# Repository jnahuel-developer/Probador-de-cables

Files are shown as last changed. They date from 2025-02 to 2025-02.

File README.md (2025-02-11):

# 🛠️ Probador de Cables  

Dispositivo para probar y validar el correcto funcionamiento de los cables que se usan en los equipos productivos.  
Este repositorio incluye tanto el firmware para el microcontrolador como el diseño del PCB.  

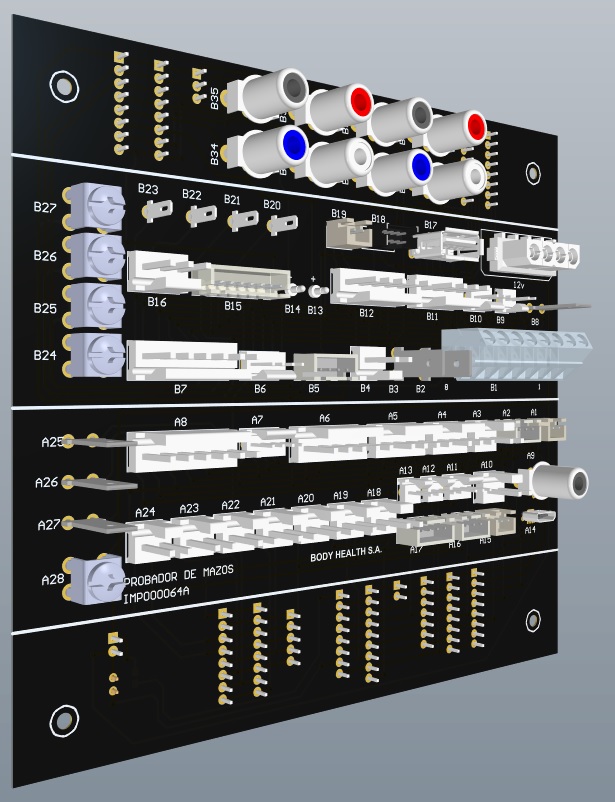
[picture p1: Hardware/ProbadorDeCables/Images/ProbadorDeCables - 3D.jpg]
Vista 3D del PCB
  

---
---

## Funcionamiento  

 Este proyecto se puede anexar al [Probador de manillares](https://github.com/jnahuel-developer/Probador-de-manillares-de-crio), para hacer uso de sus multiplexores analógicos.  
 Gracias a ellos, se puede obtener una matriz de continuidad, y analizarla según el cable en cuestión.  
 Esto permite detectar todo tipo de anormalidades, como cortocircuitos, cables cortados, o mala ubicación de algunos contactos.  

## Ejemplo de cable utilizado

Diagrama eléctrico realizado en Altium

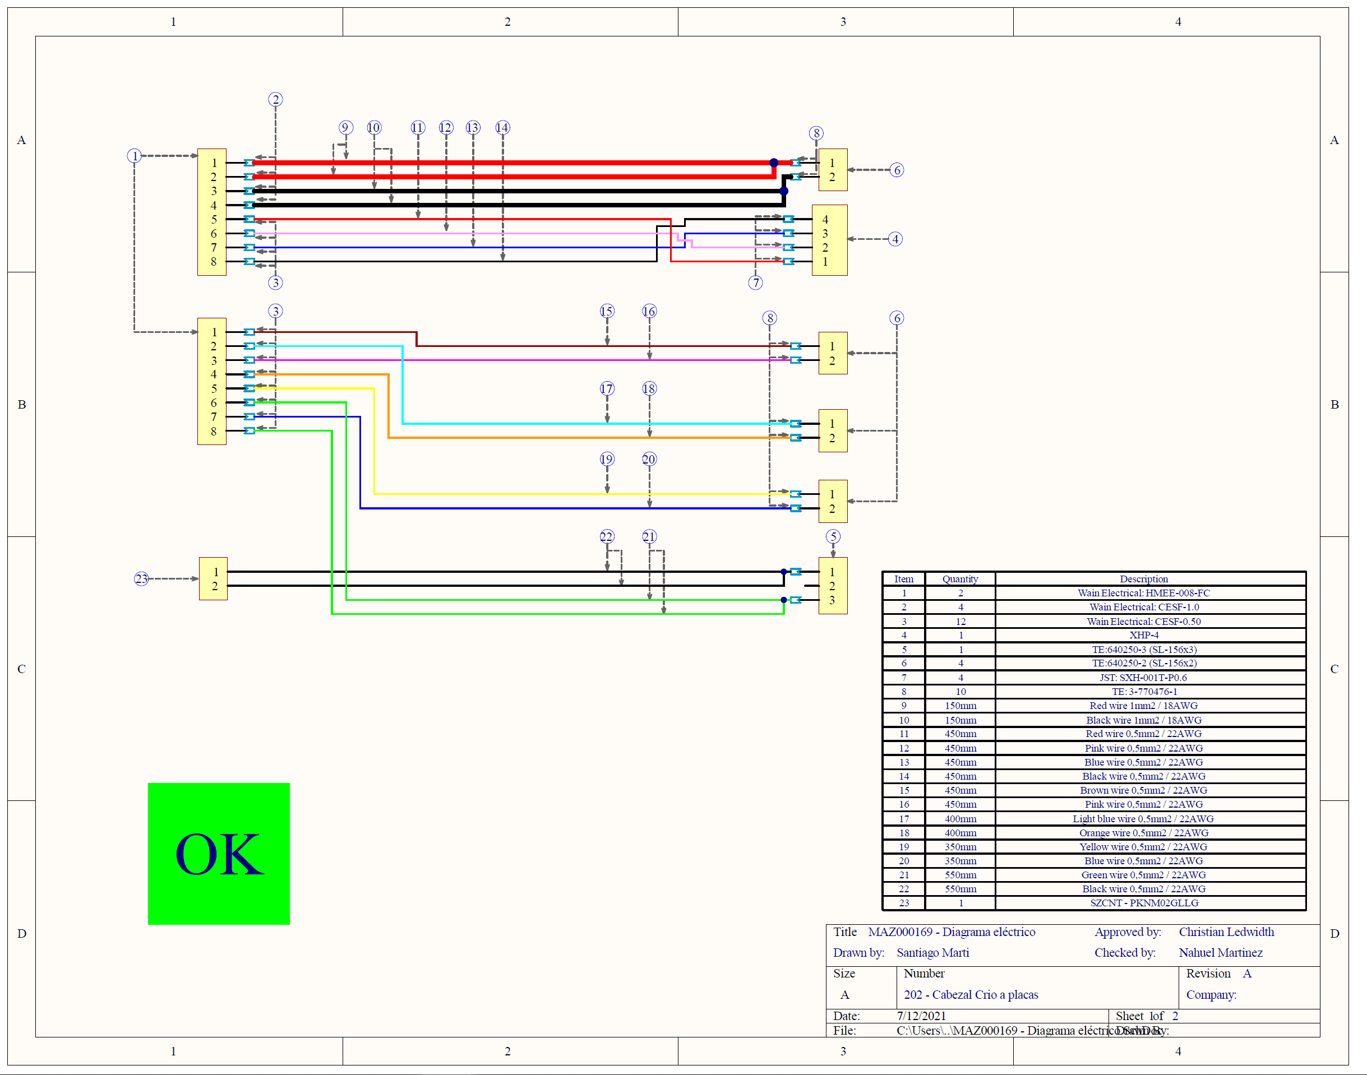
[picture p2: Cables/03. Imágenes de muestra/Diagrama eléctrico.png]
Diagrama eléctrico realizado en Altium


Diagrama físico realizado en Altium

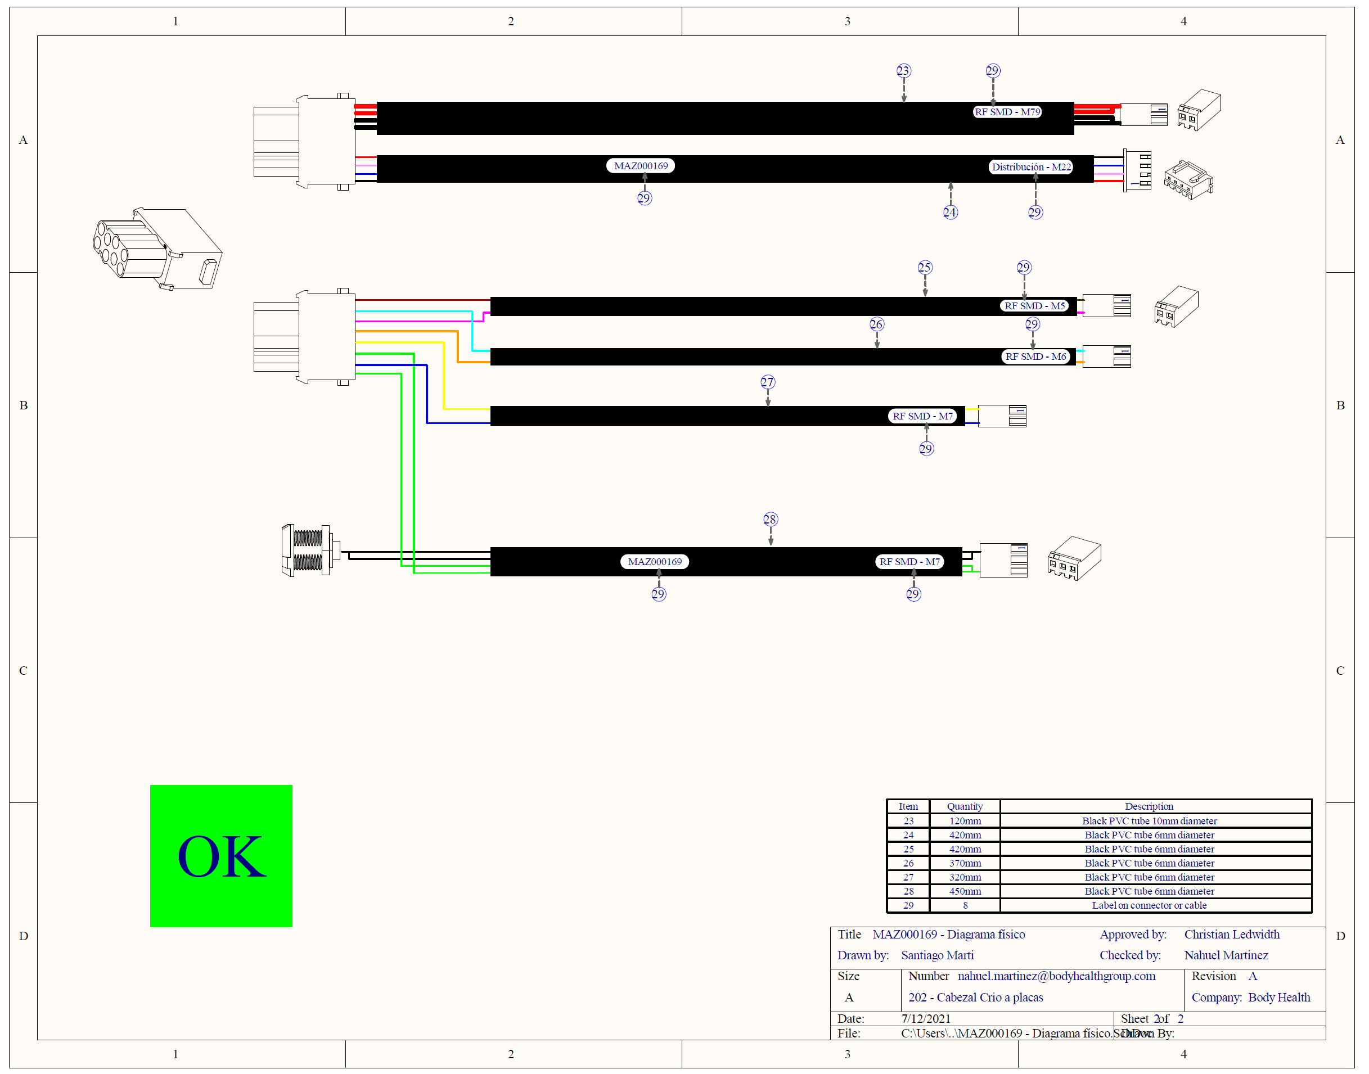
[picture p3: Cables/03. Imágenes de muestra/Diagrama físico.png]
Diagrama físico realizado en Altium


---
---

## 📁 Contenido del Repositorio  

📂 **Probador-de-cables/**  
├── 📁 **firmware/** → Código fuente para el microcontrolador  
├── 📁 **hardware/** → Diseño del PCB, esquemáticos y archivos Gerber  
├── 📜 **README.md** → Documentación principal  

---
---

## 🖼️ Modelos 3D diseñados en Altium Designer  

Vista frontal del PCB:  
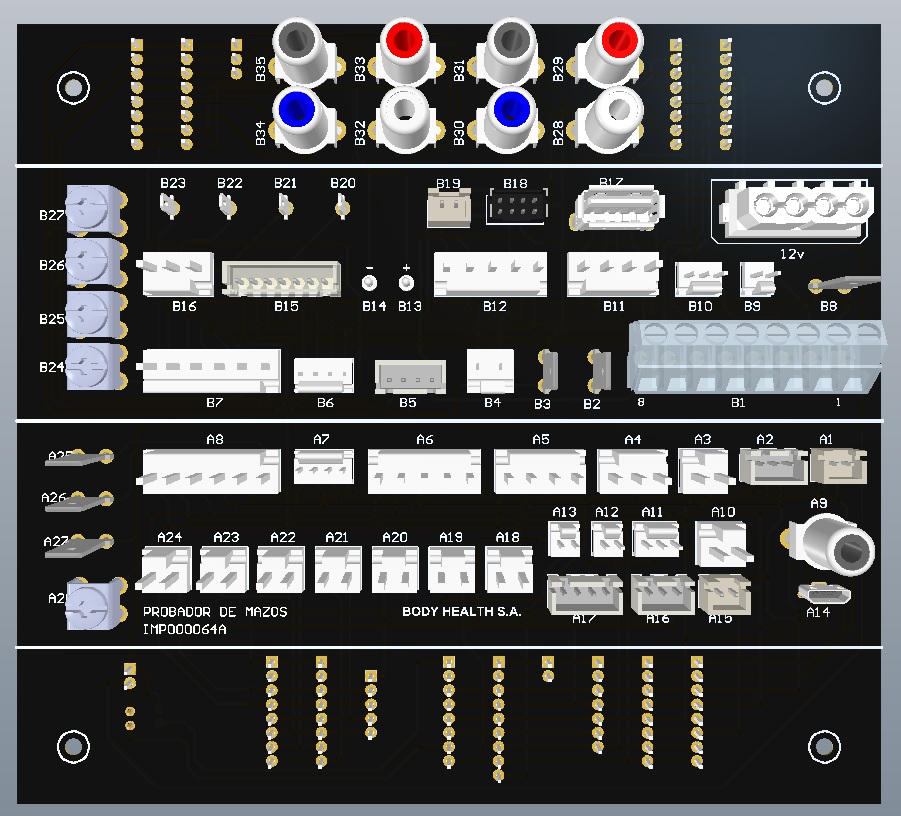
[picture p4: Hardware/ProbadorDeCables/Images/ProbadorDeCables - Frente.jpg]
Modelado frontal
  

Vista posterior del PCB:  
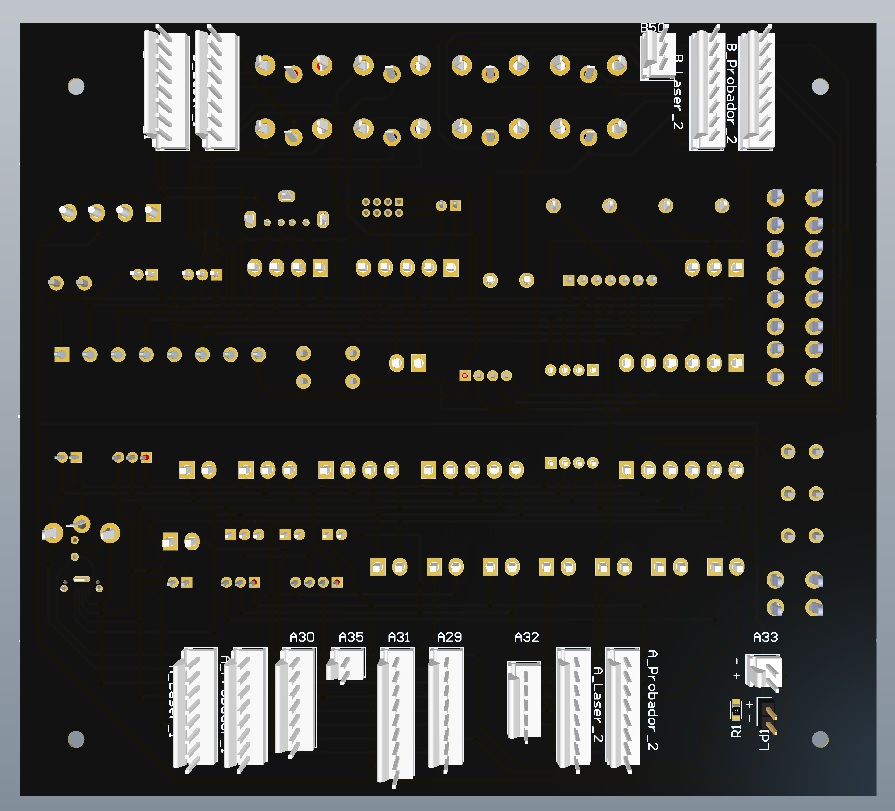
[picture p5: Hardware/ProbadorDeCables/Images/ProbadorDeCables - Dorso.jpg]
Modelado posterior
  

---
---

## 🛠️ Herramientas Utilizadas  

- **Diseño PCB** → Altium Designer  
- **Modelado 3D** → Altium Designer  
- **Firmware Target** → MC9S08AC16CFD  
- **Compiler** → CodeWarrior HCS08 C Compiler  
- **Lenguaje** → C  

---
---

📩 **Contacto:** [jnahuel.developer@gmail.com](jnahuel.developer@gmail.com)  

📩 **Contacto:** [https://www.linkedin.com/in/jnahuel/](https://www.linkedin.com/in/jnahuel/)

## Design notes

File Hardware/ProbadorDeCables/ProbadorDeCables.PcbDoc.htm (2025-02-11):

Reporting Options

# File in Previous Format

Date | : | 15/3/2021
Time | : | 21:02:35
Filename | : | F:\SVN\Dispositivos\Development\Boards\ProbadorDeCables\ProbadorDeCables.PcbDoc

Version | Warning

This file was generated by an earlier version of the software

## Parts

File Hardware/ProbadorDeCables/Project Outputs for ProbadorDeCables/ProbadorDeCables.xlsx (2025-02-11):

Cod.Digikey | Comment | Description | Designator | Footprint | Quantity
794285-1-ND | MAZ 103 y 104 | CONN HDR 4POS 0.2 TIN PCB | 12v | 794285-1 | 1
455-2247-ND | JST_2.5_2 | CONN HEADER XH TOP 2POS 2.5MM | A1, A15, B19 | B2B-XH-A | 3
455-2248-ND | JST_2.5_3 | CONN HEADER XH TOP 3POS 2.5MM | A2, A16 | B3B-XH-A | 2
A1971-ND | Para_SL-156__640445-2 | CONN HEADER VERT 2POS .156 TIN | A3, A10, A18, A19, A20, A21, A22, A23, A24, B4 | 640445-2 | 10
A19890-ND | Para_SL-156__640445-3 | CONN HEADER VERT 3POS .156 TIN | A4, B16 | 640445-3 | 2
A1972-ND | Para_SL-156__640445-4 | CONN HEADER VERT 4POS .156 TIN | A5, B11 | 640445-4 | 2
A19891-ND | Para_SL-156__640445-5 | CONN HEADER VERT 5POS .156 TIN | A6, B12 | 640445-5 | 2
A1922-ND | Para_CST_100__640456-4 | CONN HEADER VERT 4POS .100 TIN | A7, B6 | 640456-4 | 2
A1973-ND | Para_SL-156__640445-6 | CONN HEADER VERT 6POS .156 TIN | A8, B7 | 640445-6 | 2
CP-1406-ND | RCA mono para placa - Negro | CONN RCA JACK MONO 3.2MM PCB | A9, B31, B35 | RCJ-021 | 3
A19470-ND | Para_CST_100__640456-3, Interlock 3 vias gabinete | CONN HEADER VERT 3POS .100 TIN | A11, B10, B50 | 640456-3 | 3
A1921-ND | Para_CST_100__640456-2, VCC, SZCNT de 2 vías | CONN HEADER VERT 2POS .100 TIN | A12, A13, A33, A35, B9 | 640456-2 | 5
2073-USB3160-30-0170-0-CCT-ND | USB 2_0 micro B | CONN RCPT USB2.0 MICRO B SMD R/A | A14 | USB2.0_MicroB | 1
455-2249-ND | JST_2.5_4 | CONN HEADER XH TOP 4POS 2.5MM | A17, B5 | B4B-XH-A | 2
A110909CT-ND | Pala macho 6.3 para placa | CONN QC TAB 0.250 SOLDER | A25, A26, A27, B8 | Pala macho 6.3 para placa | 4
36-7795-ND | SCREW M4 4 PIN PCB, Tornillo M4 para placa | TERM SCREW M4 4 PIN PCB | A28, B24, B25, B26, B27 | SCREW M4 4 PIN PCB | 5
A1924-ND | SZCNT de 8 vías con corto, ProbadorA_1-8, ProbadorA_9-16, LaserA_1-8, LaserA_9-16, ProbadorB_1-8, ProbadorB_9-16, LaserB_1-8, LaserB_9-16 | CONN HEADER VERT 8POS .100 TIN | A29, A_Laser_1, A_Laser_2, A_Probador_1, A_Probador_2, B_Laser_1, B_Laser_2, B_Probador_1, B_Probador_2 | 640456-8 | 9
A19472-ND | SZCNT de 7 vías | CONN HEADER VERT 7POS .100 TIN | A30 | 640456-7 | 1
A19473-ND | CPC 14 por cable - A | CONN HEADER VERT 9POS .100 TIN | A31 | 640456-9 | 1
A19471-ND | CPC 14 por cable - B | CONN HEADER VERT 5POS .100 TIN | A32 | 640456-5 | 1
CP-1455-ND | RCP-023__Blanco | CONN RCA PLUG MONO 2COND | A_RCA, B_RCA, BOM_A_RCA__2, BOM_B_CPC14__1, BOM_B_CPC14__5, BOM_B_CST100__1, BOM_B_MOLEX__1, BOM_B_RCA__2, BOM_B_RJ11__1, BOM_B_SZCNT7__1, BOM_B_SZCNT8__1 | BOM_RCP-023__Blanco | 11
102-6216-ND | Bornera con tornillos 8 vías | TERMINAL BLOCK SCREW TYPE 5.08 | B1 | Bornera con tornillos 8 vías | 1
A110908CT-ND | Pala macho 4.8 para placa | CONN QC TAB 0.187 SOLDER | B2, B3 | Pala macho 4.8 para placa | 2
3-60599-1-ND | +, - | CONN PC PIN CIRC 0.058DIA TIN | B13, B14 | Pin macho para crio | 2
455-2252-ND | JST_2.5_7 | CONN HEADER XH TOP 7POS 2.5MM | B15 | B7B-XH-A | 1
WM8672-ND | USB 2_0 A | CONN RCPT USB2.0 TYPEA 4POS VERT | B17 | USB2.0_A | 1
H2852-ND | Fuente MSP-300-15 | CONN HEADER VERT 8POS 2MM | B18 | DF11-8DP-2DSA(01) | 1
A107001-ND | Pala macho 2.7 para placa | CONN QC TAB 0.110 SOLDER | B20, B21, B22, B23 | Pala macho 2.7 para placa | 4
CP-1408-ND | RCA mono para placa - Blanco | CONN RCA JACK MONO 3.2MM PCB | B28, B32 | RCJ-023 | 2
CP-1407-ND | RCA mono para placa - Rojo | CONN RCA JACK MONO 3.2MM PCB | B29, B33 | RCJ-022 | 2
CP-1410-ND | RCA mono para placa - Azul | CONN RCA JACK MONO 3.2MM PCB | B30, B34 | RCJ-025 | 2
A1358-ND | CPC14 Macho | CONN PLUG HSG MALE 14POS INLINE | B_CPC14 | BOM_CPC-14_Macho | 1
A99614-ND | CST-100-3 | CONN RCPT HSNG 3POS CST-100 II | B_CST100, BOM_B50__1 | BOM_CST-100-3 | 2
A30592-ND | Molex 6 vias 0.165 | CONN RECEPT 6POS FREE HANGING | B_MOLEX | BOM_Molex-6vias-0-165 | 1
123-A-MO6/4SF-ND | RJ11 macho para cable | CONN MOD PLUG 6P4C UNSHIELDED | B_RJ11 | BOM_RJ11-macho-para-cable | 1
Se compra a SZCNT | SZCNT_0x_Macho, SZCNT_0x_Hembra | Conector SZCNT x vías macho para cable, Conector SZCNT x vías hembra para gabinete | B_SZCNT2, B_SZCNT7, B_SZCNT8, BOM_A29, BOM_A30, BOM_A35 | BOM_SZCNT_Macho, BOM_SZCNT_Hembra | 6
A99613-ND | CST-100-2 | CONN RCPT HSNG 2POS CST-100 II | BOM__A34, BOM_A35__1 | BOM_CST-100-2 | 2
A100453CT-ND | sock_CST_1375819-1 | CONN SOCKET 22-26AWG CRIMP TIN | BOM__A34__1, BOM__A34__2, BOM_A29__2, BOM_A29__3, BOM_A29__4, BOM_A29__5, BOM_A29__6, BOM_A29__7, BOM_A29__8, BOM_A29__9, BOM_A30__2, BOM_A30__3, BOM_A30__4, BOM_A30__5, BOM_A30__6, BOM_A30__7, BOM_A30__8, BOM_A30_A31__17, BOM_A30_A31__18, BOM_A30_A31__19, BOM_A30_A31__20, BOM_A30_A31__21, BOM_A30_A31__22, BOM_A30_A31__23, BOM_A30_A31__24, BOM_A30_A31__25, BOM_A30_A31__26, BOM_A30_A31__27, BOM_A30_A31__28, BOM_A30_A31__29, BOM_A30_A31__30, BOM_A35__2, BOM_A35__3, BOM_B50__2, BOM_B50__3, BOM_B50__4, BOM_B_CST100__3, BOM_B_CST100__4, BOM_B_CST100__5 | BOM_sock_CST_1375819-1 | 39
A99618-ND | CST-100-8 | CONN RCPT HSNG 8POS CST-100 II | BOM_A29__1 | BOM_CST-100-8 | 1
A112102-ND | CST-100-7 | CONN RCPT HSNG 7POS CST-100 II | BOM_A30__1 | BOM_CST-100-7 | 1
A1362-ND | CPC14 Hembra | CONN RCPT HSG FMALE 14POS PNL MT | BOM_A30_A31 | BOM_CPC-14_Hembra | 1
A25128-ND | sock_CPC-Hembra_66360-3 | CONN SOCKET 18-24AWG CRIMP TIN | BOM_A30_A31__1, BOM_A30_A31__2, BOM_A30_A31__3, BOM_A30_A31__4, BOM_A30_A31__5, BOM_A30_A31__6, BOM_A30_A31__7, BOM_A30_A31__8, BOM_A30_A31__9, BOM_A30_A31__10, BOM_A30_A31__11, BOM_A30_A31__12, BOM_A30_A31__13, BOM_A30_A31__14 | BOM_sock_CPC14_Hembra | 14
A99616-ND | CST-100-5 | CONN RCPT HSNG 5POS CST-100 II | BOM_A30_A31__15 | BOM_CST-100-5 | 1
A99619-ND | CST-100-9 | CONN RCPT HSNG 9POS CST-100 II | BOM_A30_A31__16 | BOM_CST-100-9 | 1
952-2227-ND | Rectangular_100-2 | CONN RCPT HSG 2POS 2.54MM | BOM_A34 | BOM_M20-1060200 | 1
952-2159-ND | sock_M20-1060200 | CONN SOCKET 22-30AWG CRIMP TIN | BOM_A34__1, BOM_A34__2 | BOM_sock_Rect_M20-1180046 | 2
751-1114-ND | LED_5mm_Verde | LED GREEN DIFFUSED 5MM T/H | BOM_A34__3 | BOM_LED-Verde-5mm | 1
67-1332-ND | Porta Leds 5mm | HOLDER LED PANEL 5MM BLACK NYLON | BOM_A34__4 | BOM_Porta-LED-5mm | 1
Q212-ND | Interlock macho para gabinete | PWR ENT RCPT IEC320-C14 PANEL QC | BOM_B50 | BOM_703W-00/04 | 1
CP-1454-ND | RCP-022__Rojo | CONN RCA PLUG MONO 2COND | BOM_B_CPC14__2, BOM_B_CPC14__6, BOM_B_CST100__2, BOM_B_MOLEX__2, BOM_B_RJ11__2, BOM_B_SZCNT7__2, BOM_B_SZCNT8__2 | BOM_RCP-022__Rojo | 7
CP-1457-ND | RCP-025__Azul | CONN RCA PLUG MONO 2COND | BOM_B_CPC14__3, BOM_B_CPC14__7, BOM_B_MOLEX__3, BOM_B_SZCNT7__3, BOM_B_SZCNT8__3 | BOM_RCP-025__Azul | 5
CP-1453-ND | RCP-021__Negro | CONN RCA PLUG MONO 2COND | BOM_B_CPC14__4, BOM_B_SZCNT2, BOM_B_SZCNT7__4, BOM_B_SZCNT8__4 | BOM_RCP-021__Negro | 4
A25127CT-ND | sock_CPC-Macho_66359-9 | CONN PIN 14-18AWG GOLD CRIMP | BOM_B_CPC14__9, BOM_B_CPC14__10, BOM_B_CPC14__11, BOM_B_CPC14__12, BOM_B_CPC14__13, BOM_B_CPC14__14, BOM_B_CPC14__15, BOM_B_CPC14__16, BOM_B_CPC14__17, BOM_B_CPC14__18, BOM_B_CPC14__19, BOM_B_CPC14__20, BOM_B_CPC14__21, BOM_B_CPC14__22 | BOM_sock_CPC14_Macho | 14
A30638-ND | sock_Molex_1586317-1 | CONN SOCKET 22-26AWG CRIMP TIN | BOM_B_MOLEX__4, BOM_B_MOLEX__5, BOM_B_MOLEX__6, BOM_B_MOLEX__7, BOM_B_MOLEX__8, BOM_B_MOLEX__9 | BOM_sock_Molex_1586317-1 | 6
732-5315-ND | PinesParaLed | CONN HEADER 2 POS 2.54 | Ld1 | Jumper-Simple | 1
311-330CRCT-ND | 330 | RES SMD 330 OHM 1% 1/8W 0805 | R1 | R_0805 | 1

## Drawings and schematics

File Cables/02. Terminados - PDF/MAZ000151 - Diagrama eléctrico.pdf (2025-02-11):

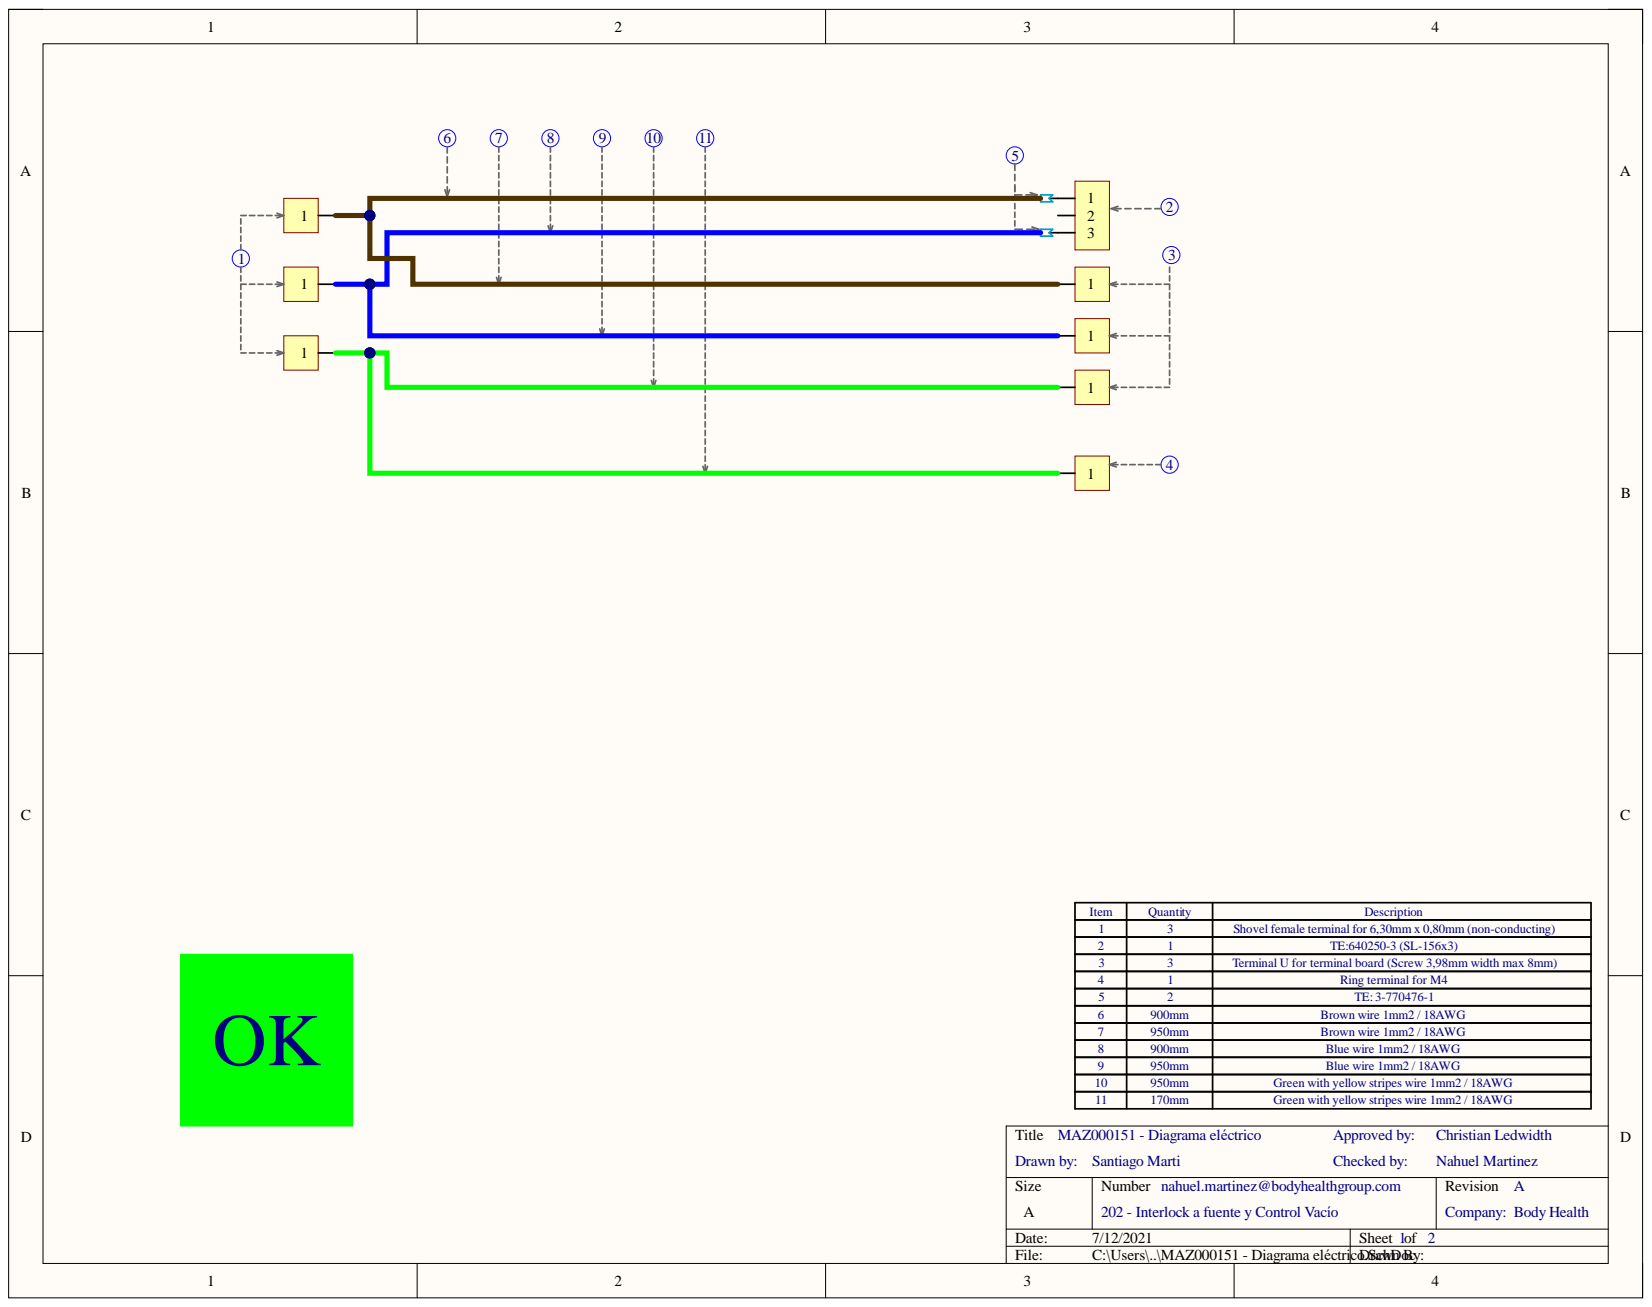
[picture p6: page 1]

Item | Quantity | Description
1 | 3 | Shovel female terminal for 6,30mm x 0,80mm (non-conducting)
2 | 1 | TE:640250-3 (SL-156x3)

4 | 1 | Ring terminal for M4
5 | 2 | TE: 3-770476-1
6 | 900mm | Brown wire 1mm2 / 18AWG
7 | 950mm | Brown wire 1mm2 / 18AWG
8 | 900mm | Blue wire 1mm2 / 18AWG
9 | 950mm | Blue wire 1mm2 / 18AWG
10 | 950mm | Green with yellow stripes wire 1mm2 / 18AWG
11 | 170mm | Green with yellow stripes wire 1mm2 / 18AWG

Size A | Number nahuel.martinez@bodyhealthgroup.com 202 - Interlock a fuente y Control Vacío | Revision A Company: Body Health

Date: 7/12/2021 | Sheet of 1 2
File: C:\Users\..\MAZ000151 - Diagrama eléctricoDr.ScawhDon Bcy:

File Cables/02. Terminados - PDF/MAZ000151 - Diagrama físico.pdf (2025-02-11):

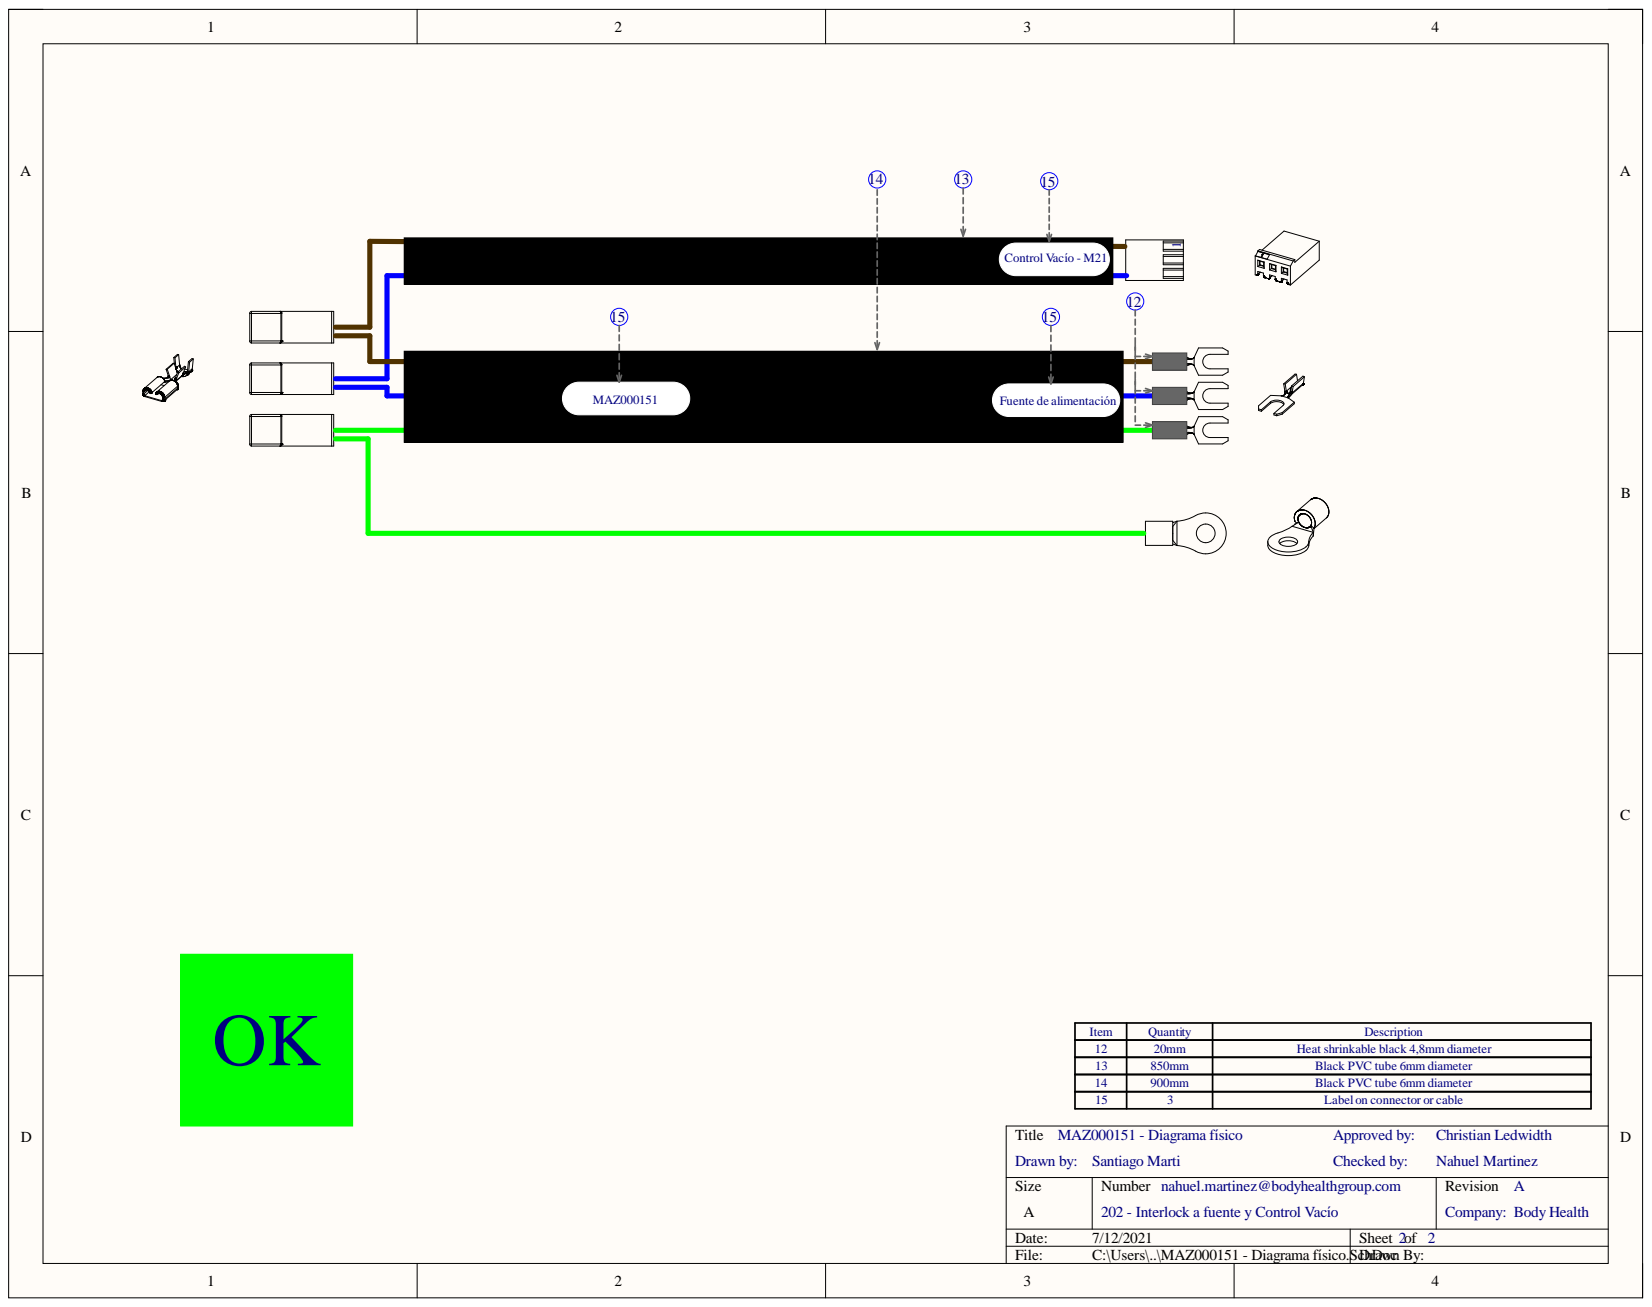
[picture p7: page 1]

Item | Quantity | Description
12 | 20mm | Heat shrinkable black 4,8mm diameter
13 | 850mm | Black PVC tube 6mm diameter

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

Date: 7/12/2021 | Sheet of 2 2
File: C:\Users\..\MAZ000151 - Diagrama físico.ScDrhDoawcn By:

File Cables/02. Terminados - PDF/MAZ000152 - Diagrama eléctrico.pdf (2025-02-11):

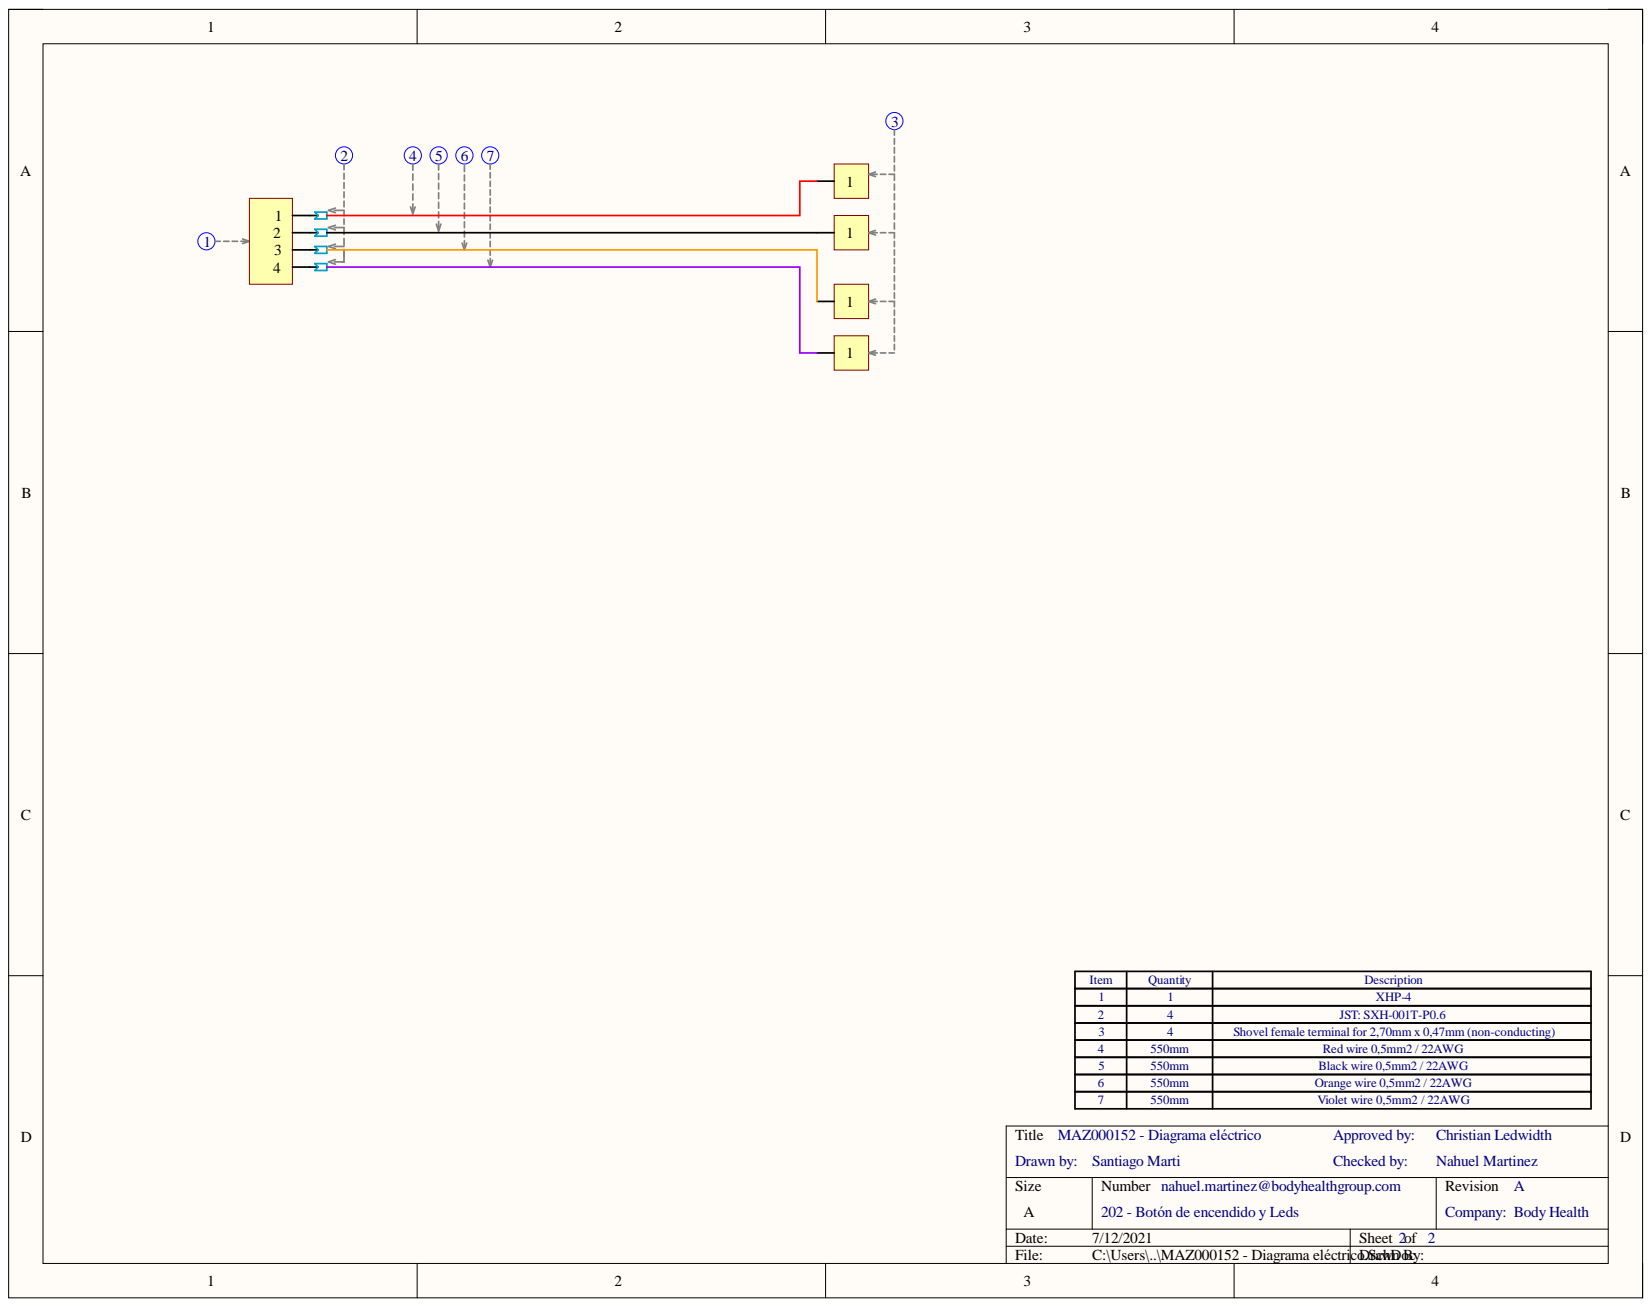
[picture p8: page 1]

Item | Quantity | Description
1 | 1 | XHP-4
2 | 4 | JST: SXH-001T-P0.6
3 | 4 | Shovel female terminal for 2,70mm x 0,47mm (non-conducting)
4 | 550mm | Red wire 0,5mm2 / 22AWG
5 | 550mm | Black wire 0,5mm2 / 22AWG
6 | 550mm | Orange wire 0,5mm2 / 22AWG
7 | 550mm | Violet wire 0,5mm2 / 22AWG

Size A | Number nahuel.martinez@bodyhealthgroup.com 202 - Botón de encendido y Leds | Revision A Company: Body Health

Date: 7/12/2021 | Sheet of 2 2
File: C:\Users\..\MAZ000152 - Diagrama eléctricoDr.ScawhDon Bcy:

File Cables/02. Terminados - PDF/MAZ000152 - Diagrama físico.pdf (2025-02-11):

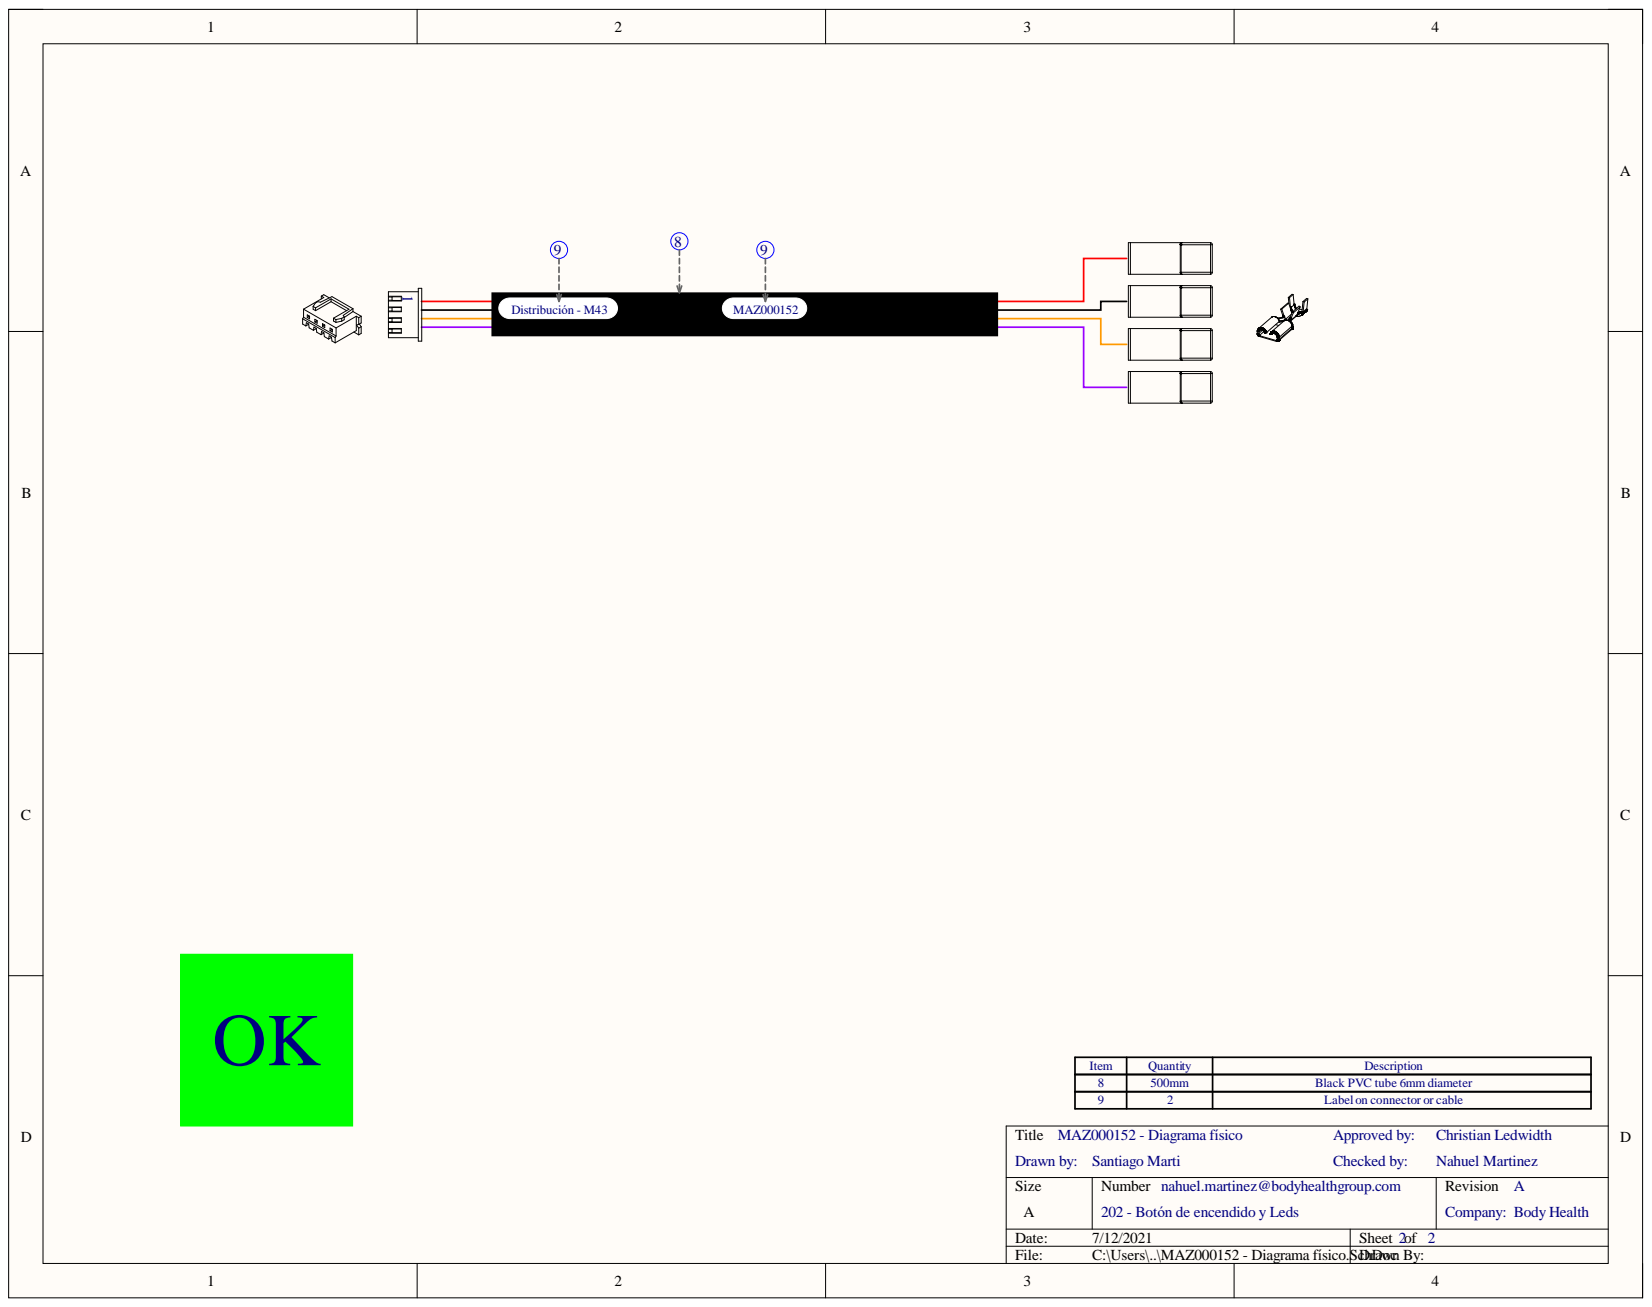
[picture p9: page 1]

Item | Quantity | Description
8 | 500mm | Black PVC tube 6mm diameter
9 | 2 | Label on connector or cable

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

Date: 7/12/2021 | Sheet of 2 2
File: C:\Users\..\MAZ000152 - Diagrama físico.ScDrhDoawcn By:

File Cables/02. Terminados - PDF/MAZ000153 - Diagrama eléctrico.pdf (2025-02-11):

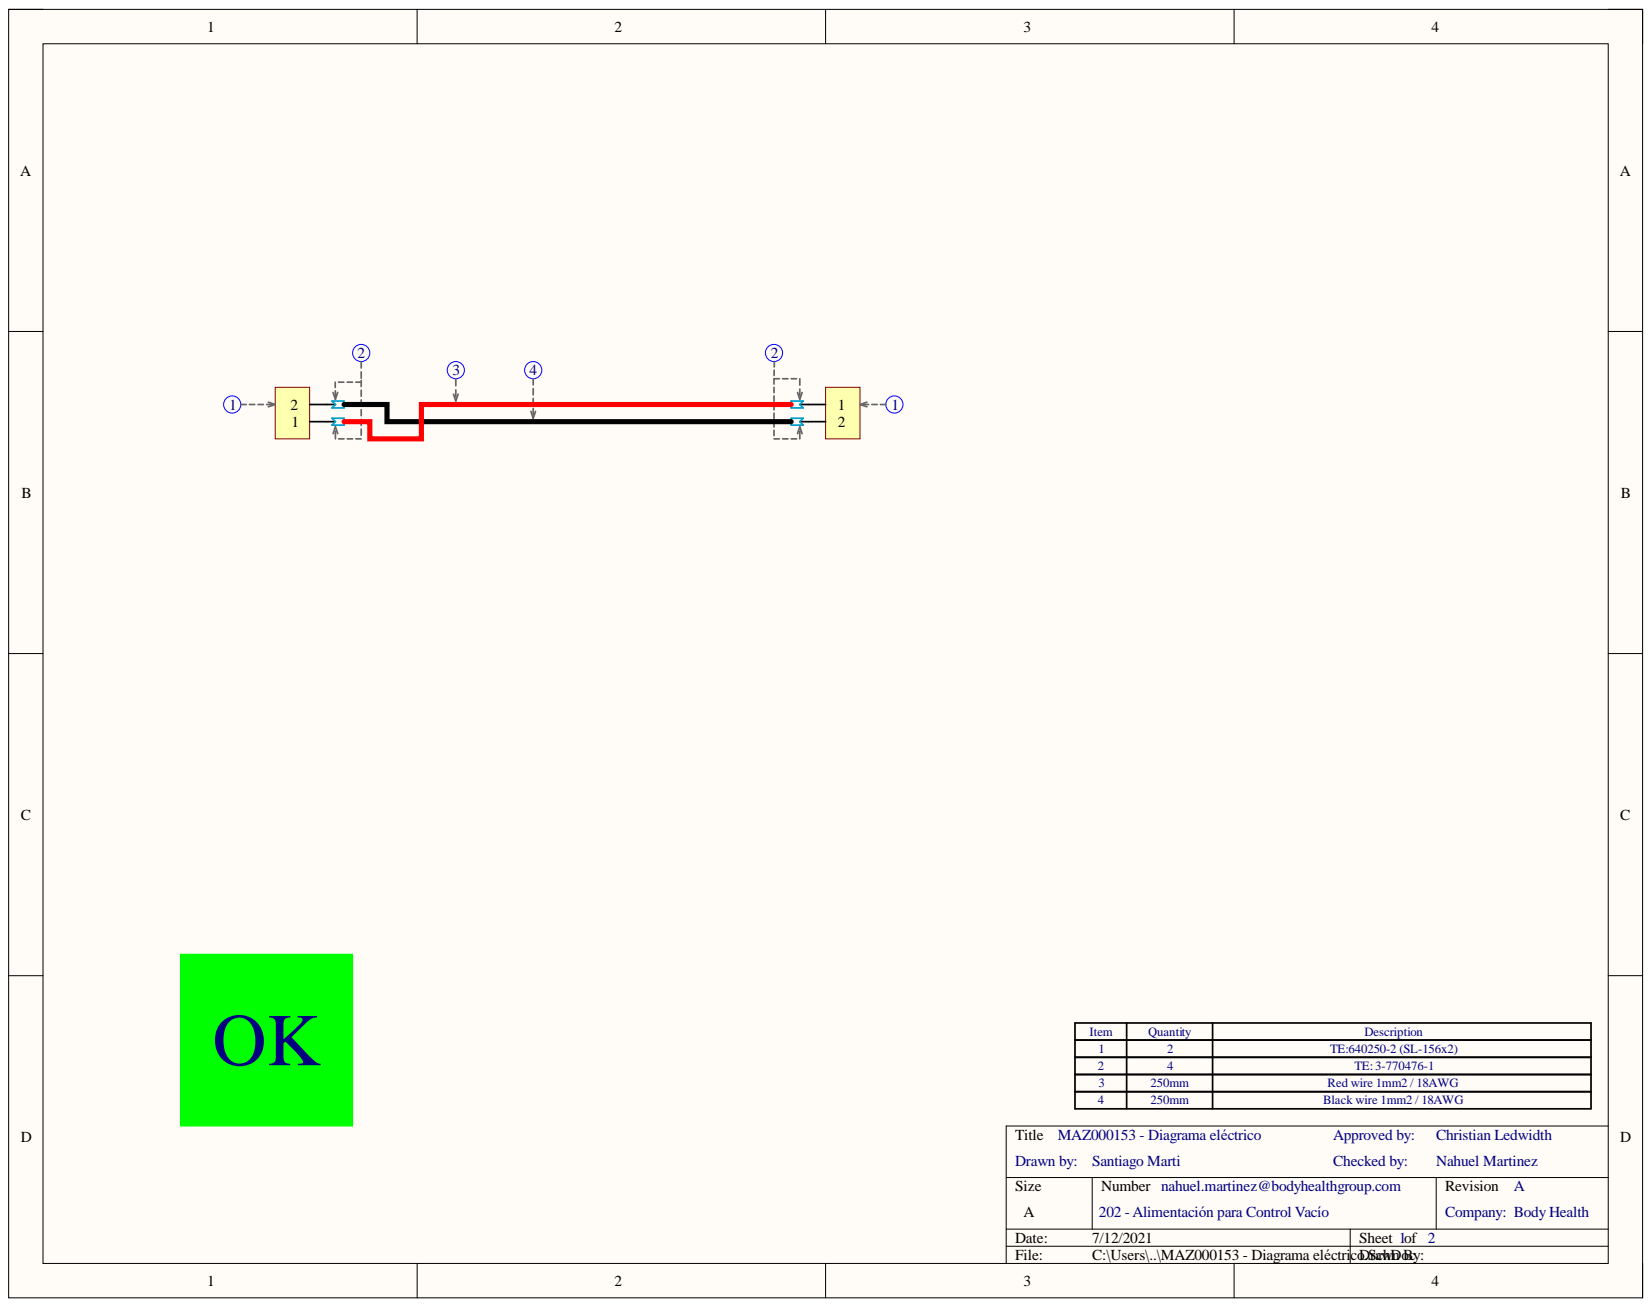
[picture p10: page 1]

Item | Quantity | Description
1 | 2 | TE:640250-2 (SL-156x2)
2 | 4 | TE: 3-770476-1
3 | 250mm | Red wire 1mm2 / 18AWG
4 | 250mm | Black wire 1mm2 / 18AWG

Size A | Number nahuel.martinez@bodyhealthgroup.com 202 - Alimentación para Control Vacío | Revision A Company: Body Health

Date: 7/12/2021 | Sheet of 1 2
File: C:\Users\..\MAZ000153 - Diagrama eléctricoDr.ScawhDon Bcy:

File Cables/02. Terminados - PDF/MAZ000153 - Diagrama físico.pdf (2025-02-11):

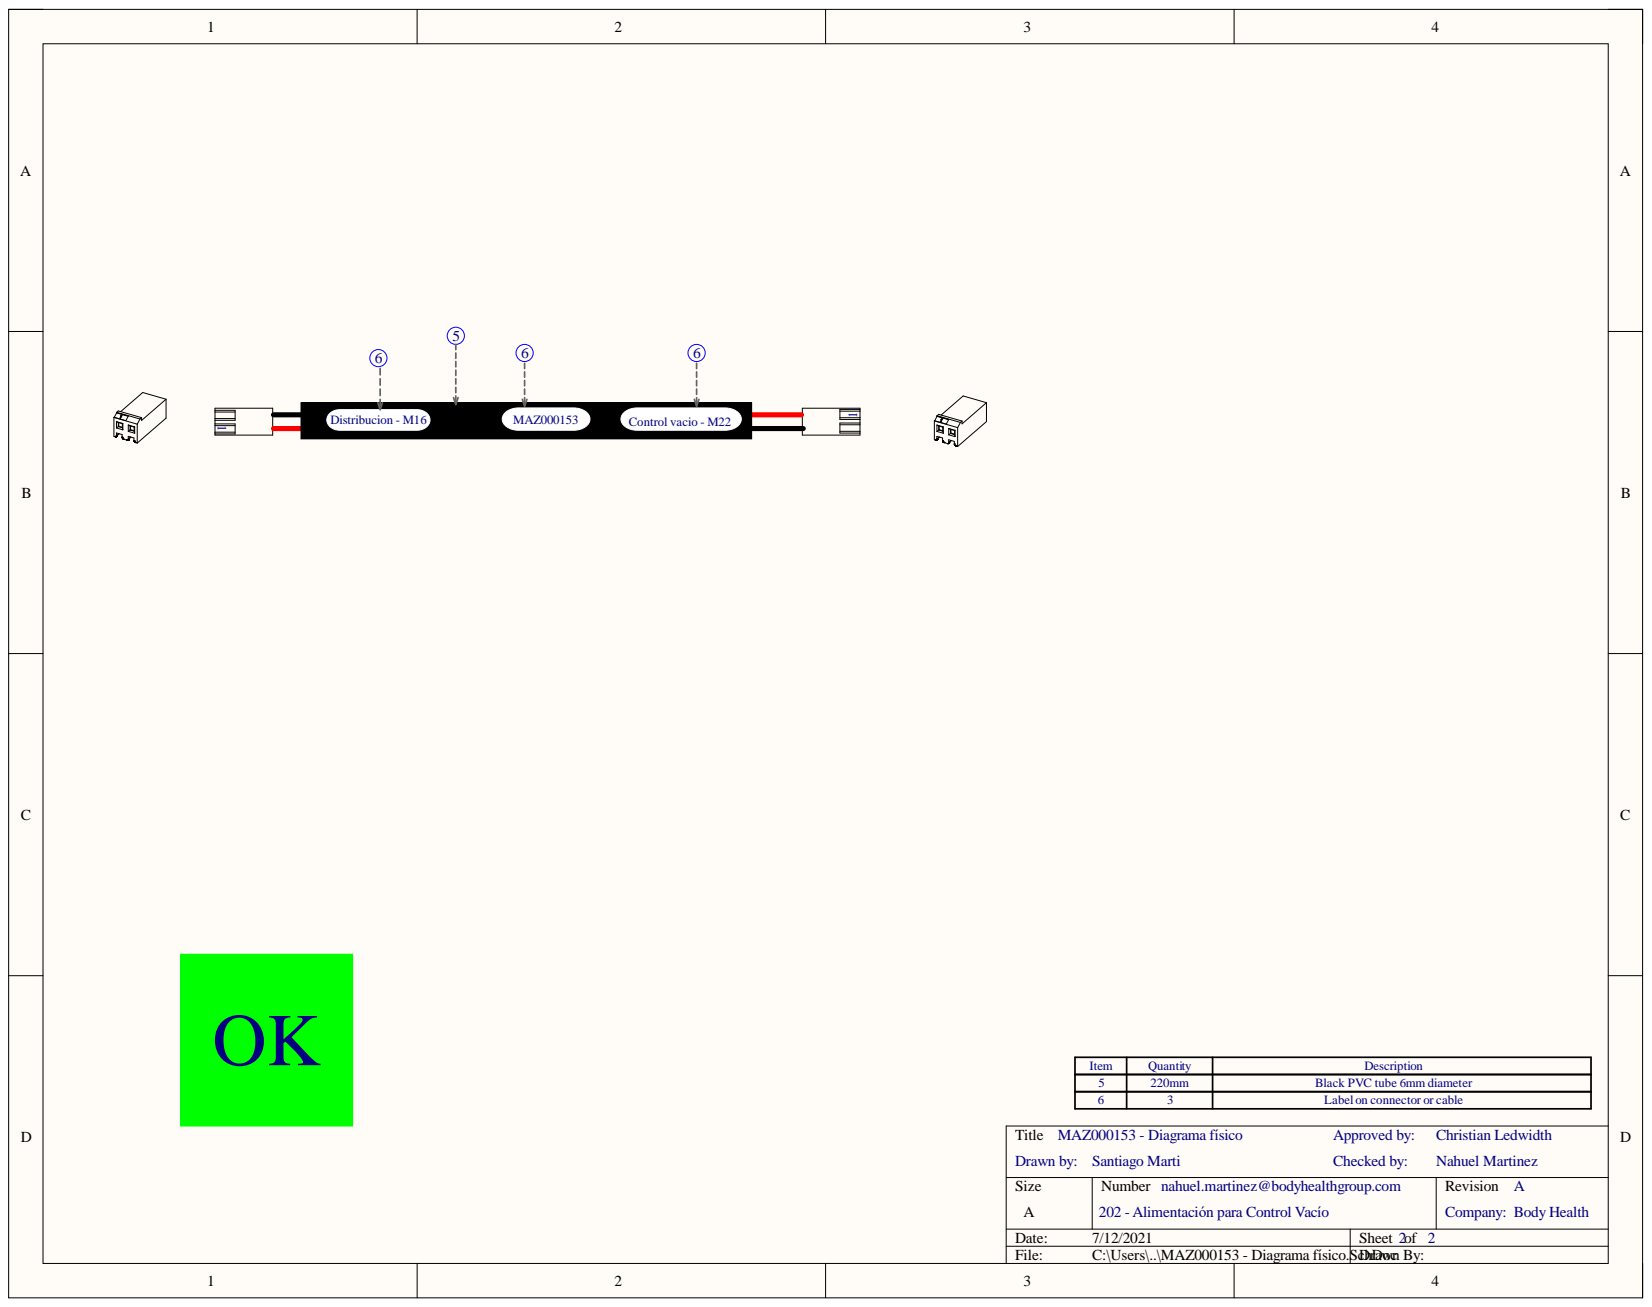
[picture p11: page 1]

Item | Quantity | Description
5 | 220mm | Black PVC tube 6mm diameter
6 | 3 | Label on connector or cable

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

Date: 7/12/2021 | Sheet of 2 2
File: C:\Users\..\MAZ000153 - Diagrama físico.ScDrhDoawcn By:

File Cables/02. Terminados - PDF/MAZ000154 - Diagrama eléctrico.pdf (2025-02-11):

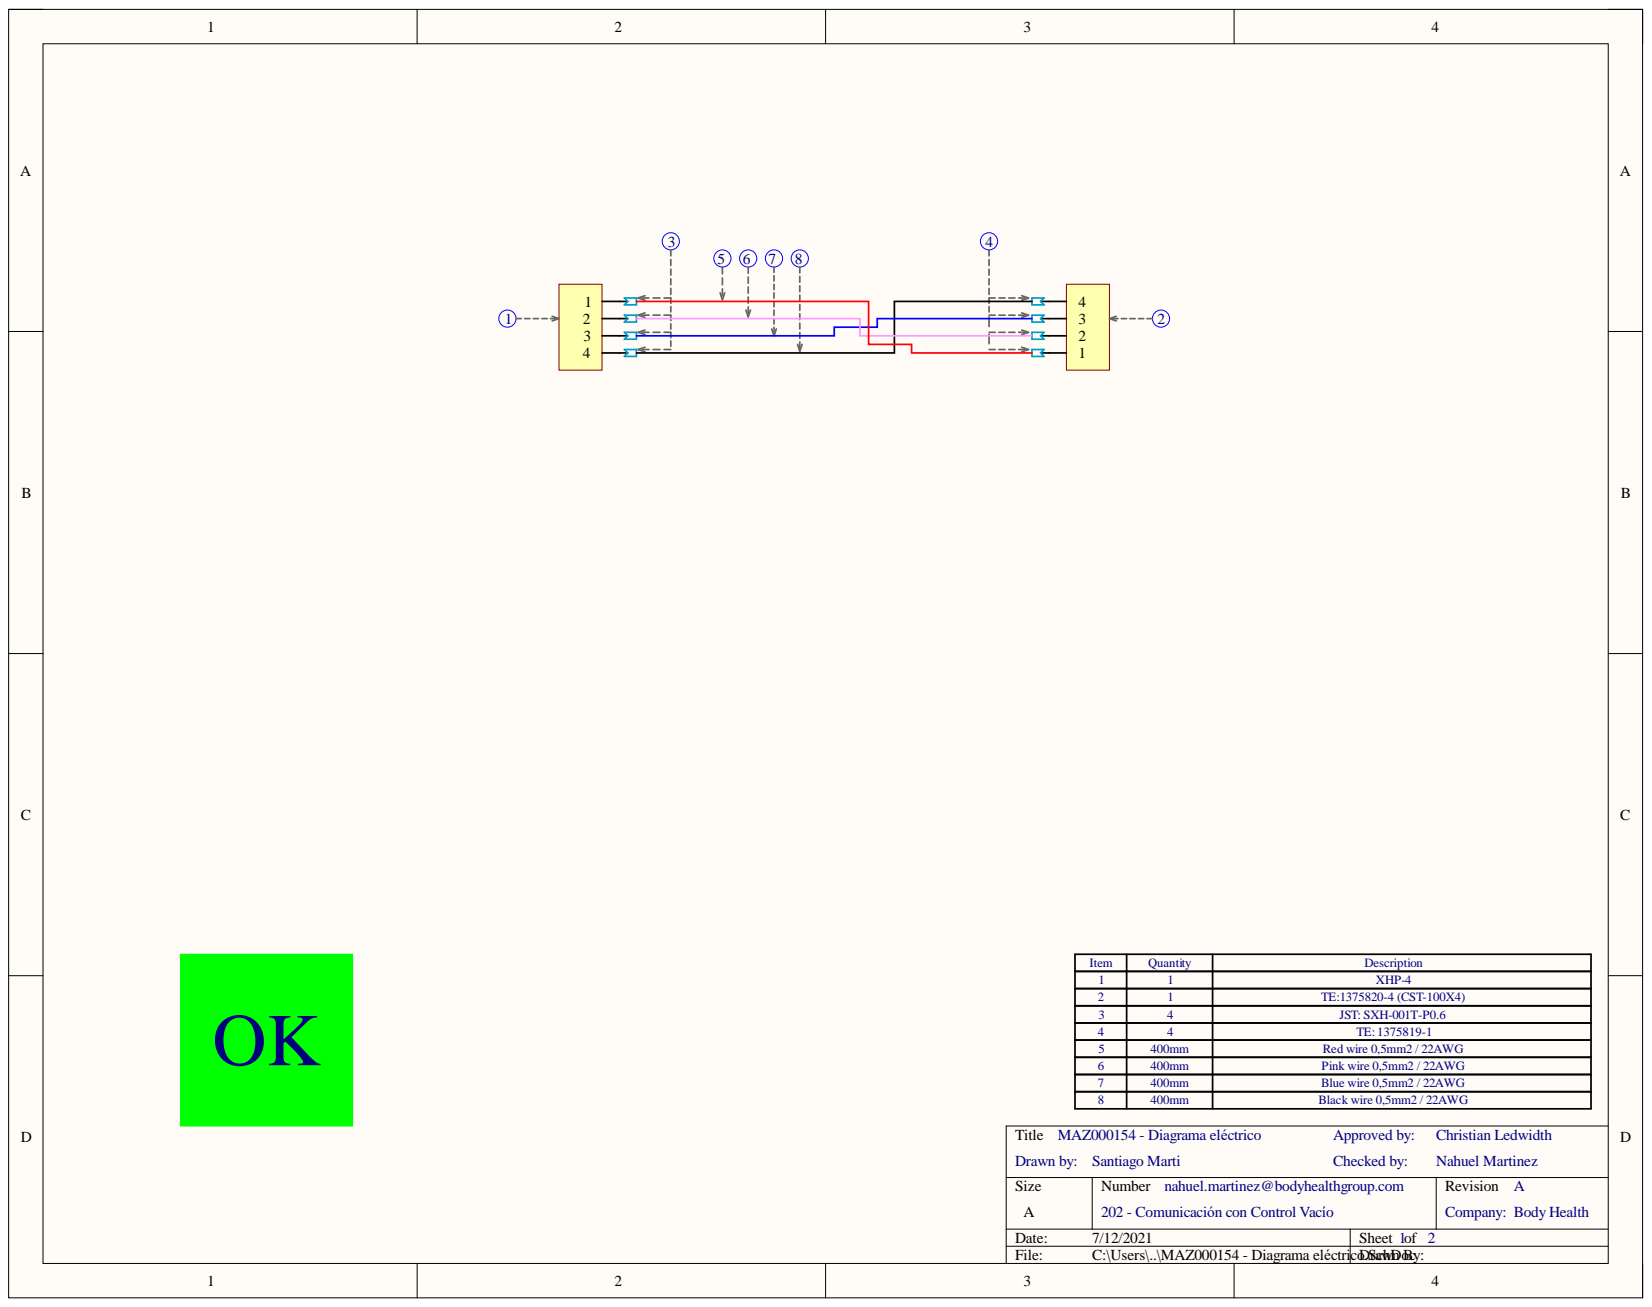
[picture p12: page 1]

1 | 1 | XHP-4
2 | 1 | TE:1375820-4 (CST-100X4)
3 | 4 | JST: SXH-001T-P0.6
4 | 4 | TE: 1375819-1
5 | 400mm | Red wire 0,5mm2 / 22AWG
6 | 400mm | Pink wire 0,5mm2 / 22AWG
7 | 400mm | Blue wire 0,5mm2 / 22AWG
8 | 400mm | Black wire 0,5mm2 / 22AWG

Size A | Number nahuel.martinez@bodyhealthgroup.com 202 - Comunicación con Control Vacío | Revision A Company: Body Health

Date: 7/12/2021 | Sheet of 1 2
File: C:\Users\..\MAZ000154 - Diagrama eléctricoDr.ScawhDon Bcy:

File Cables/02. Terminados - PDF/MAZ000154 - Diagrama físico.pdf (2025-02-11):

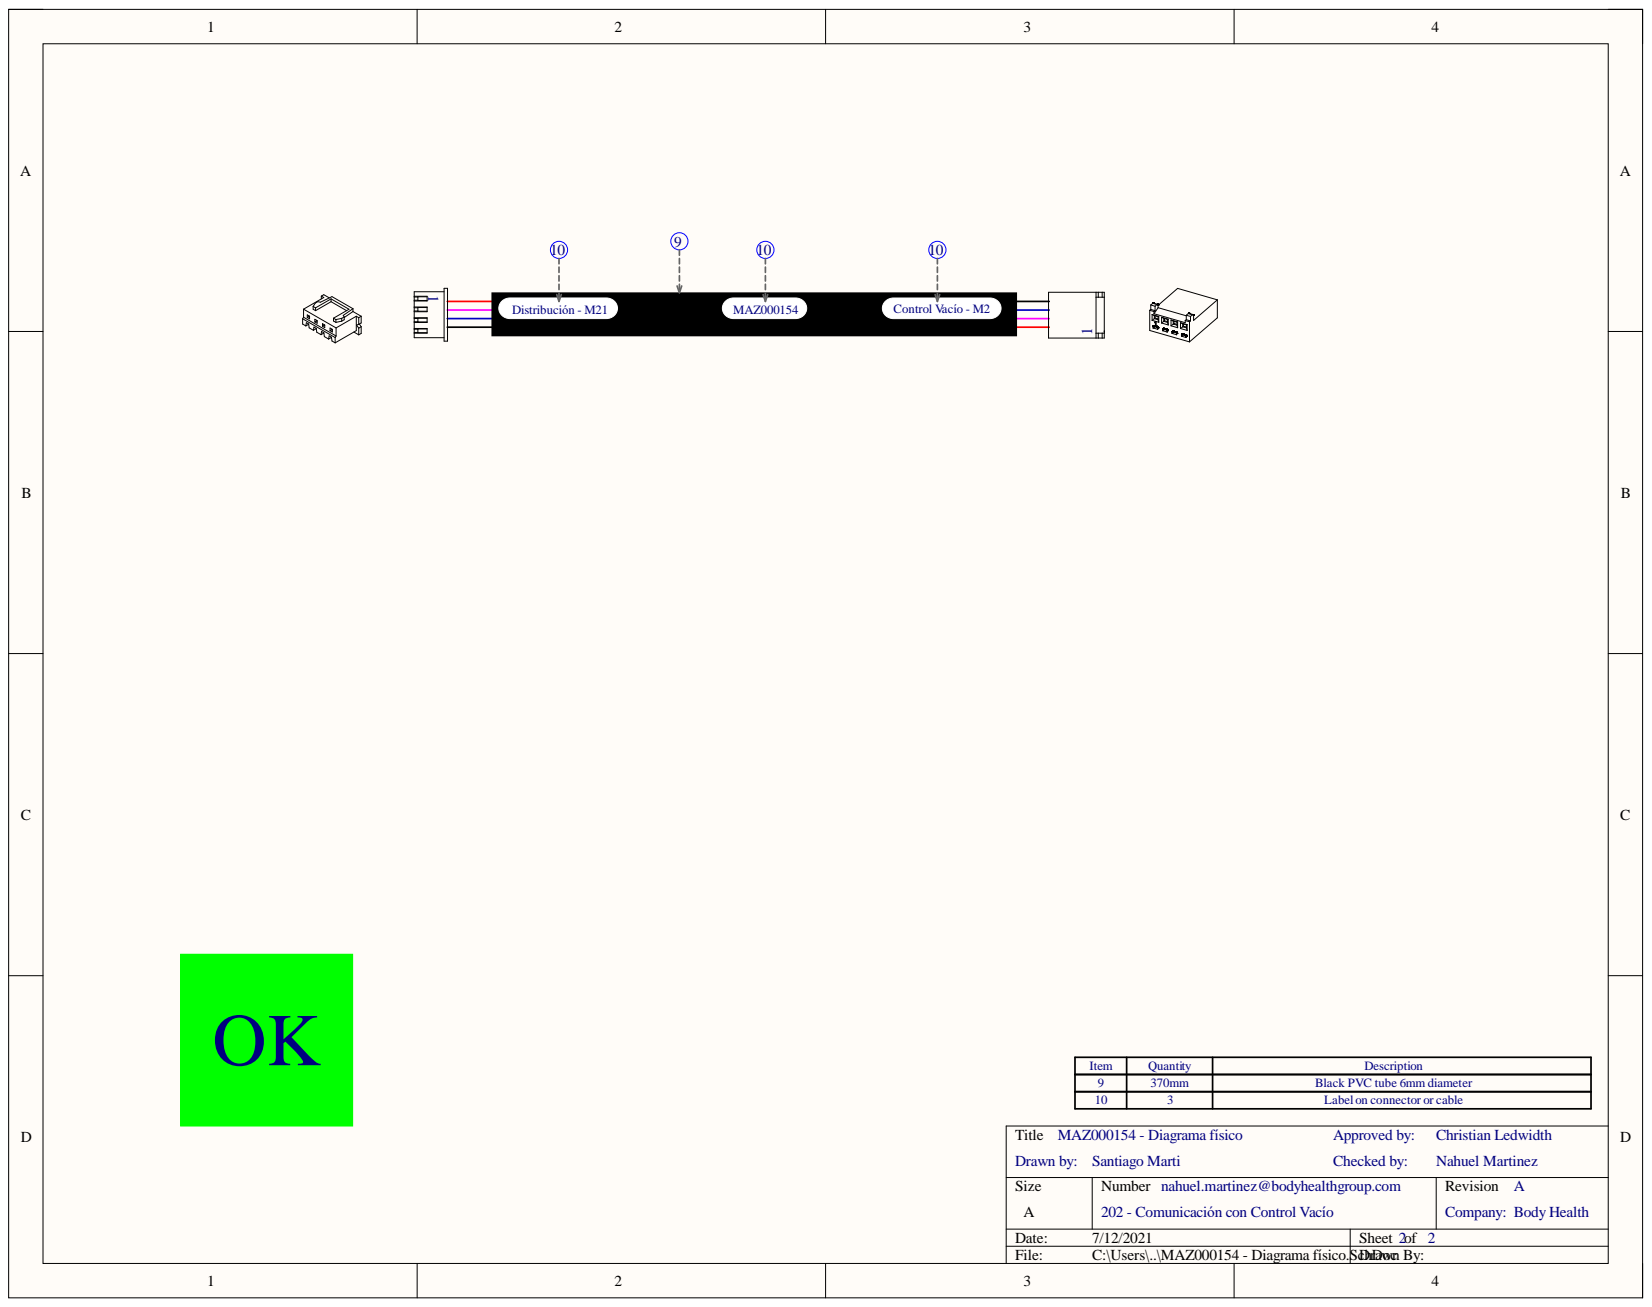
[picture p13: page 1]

Item | Quantity | Description
9 | 370mm | Black PVC tube 6mm diameter
10 | 3 | Label on connector or cable

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

Date: 7/12/2021 | Sheet of 2 2
File: C:\Users\..\MAZ000154 - Diagrama físico.ScDrhDoawcn By:

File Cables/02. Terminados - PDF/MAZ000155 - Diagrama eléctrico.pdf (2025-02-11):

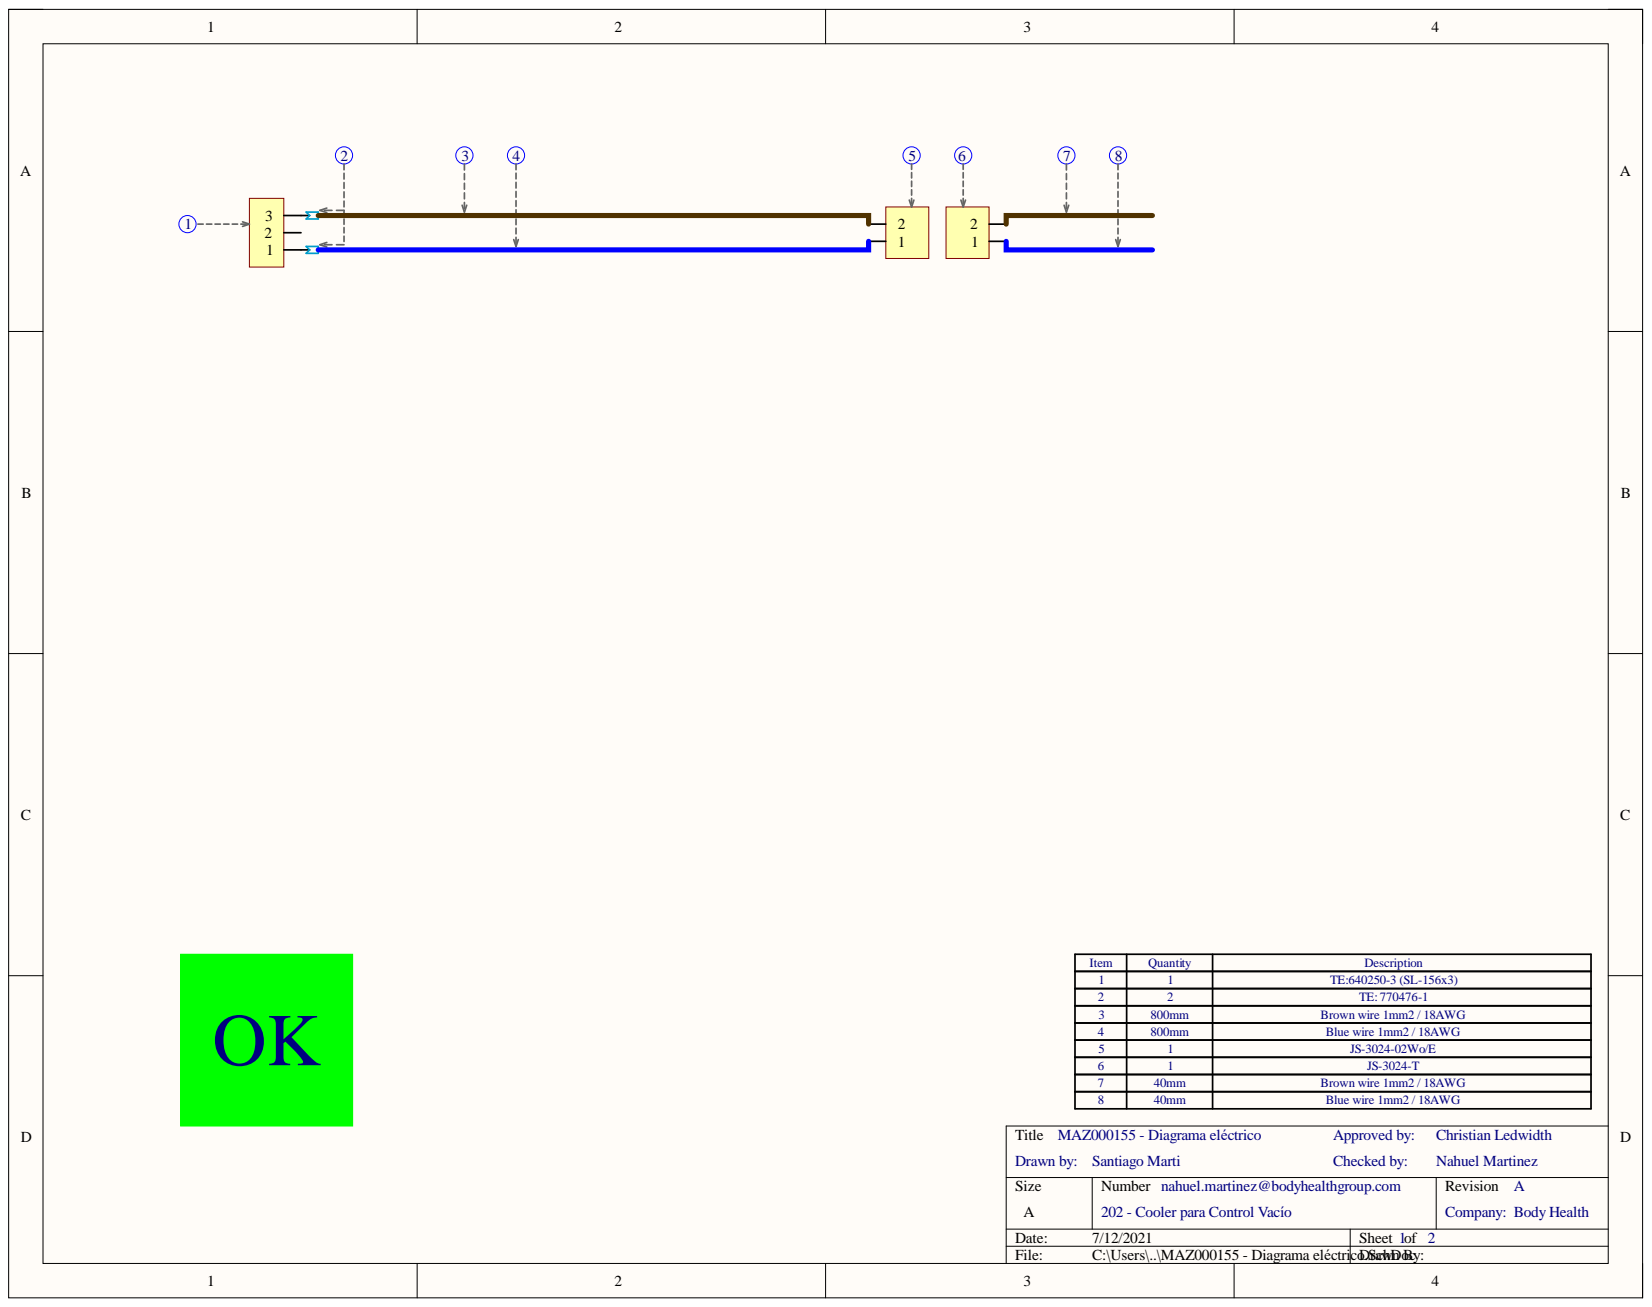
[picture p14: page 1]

1 | 1 | TE:640250-3 (SL-156x3)
2 | 2 | TE: 770476-1
3 | 800mm | Brown wire 1mm2 / 18AWG
4 | 800mm | Blue wire 1mm2 / 18AWG
5 | 1 | JS-3024-02Wo/E
6 | 1 | JS-3024-T
7 | 40mm | Brown wire 1mm2 / 18AWG
8 | 40mm | Blue wire 1mm2 / 18AWG

Size A | Number nahuel.martinez@bodyhealthgroup.com 202 - Cooler para Control Vacío | Revision A Company: Body Health

Date: 7/12/2021 | Sheet of 1 2
File: C:\Users\..\MAZ000155 - Diagrama eléctricoDr.ScawhDon Bcy:

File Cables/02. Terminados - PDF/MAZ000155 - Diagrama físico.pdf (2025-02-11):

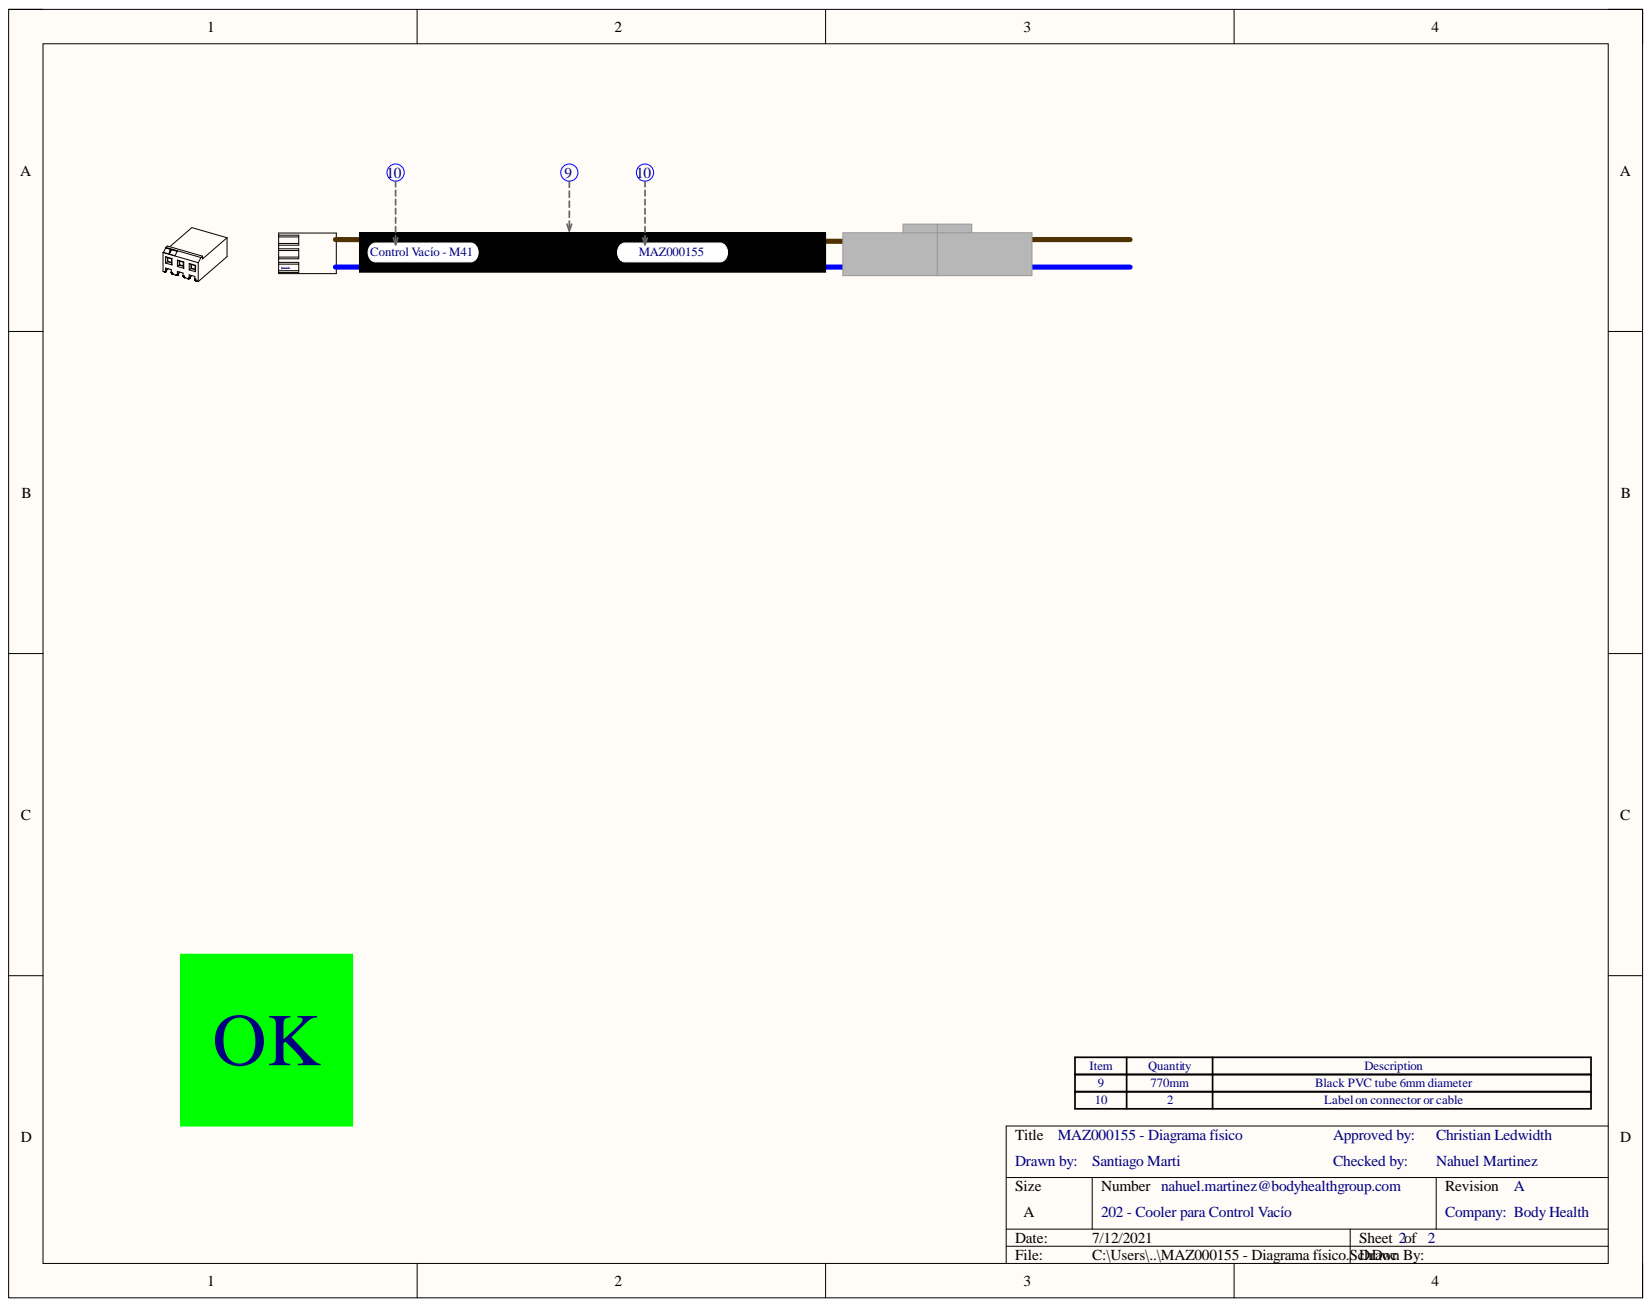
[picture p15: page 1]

Item | Quantity | Description
9 | 770mm | Black PVC tube 6mm diameter
10 | 2 | Label on connector or cable

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

Date: 7/12/2021 | Sheet of 2 2
File: C:\Users\..\MAZ000155 - Diagrama físico.ScDrhDoawcn By:

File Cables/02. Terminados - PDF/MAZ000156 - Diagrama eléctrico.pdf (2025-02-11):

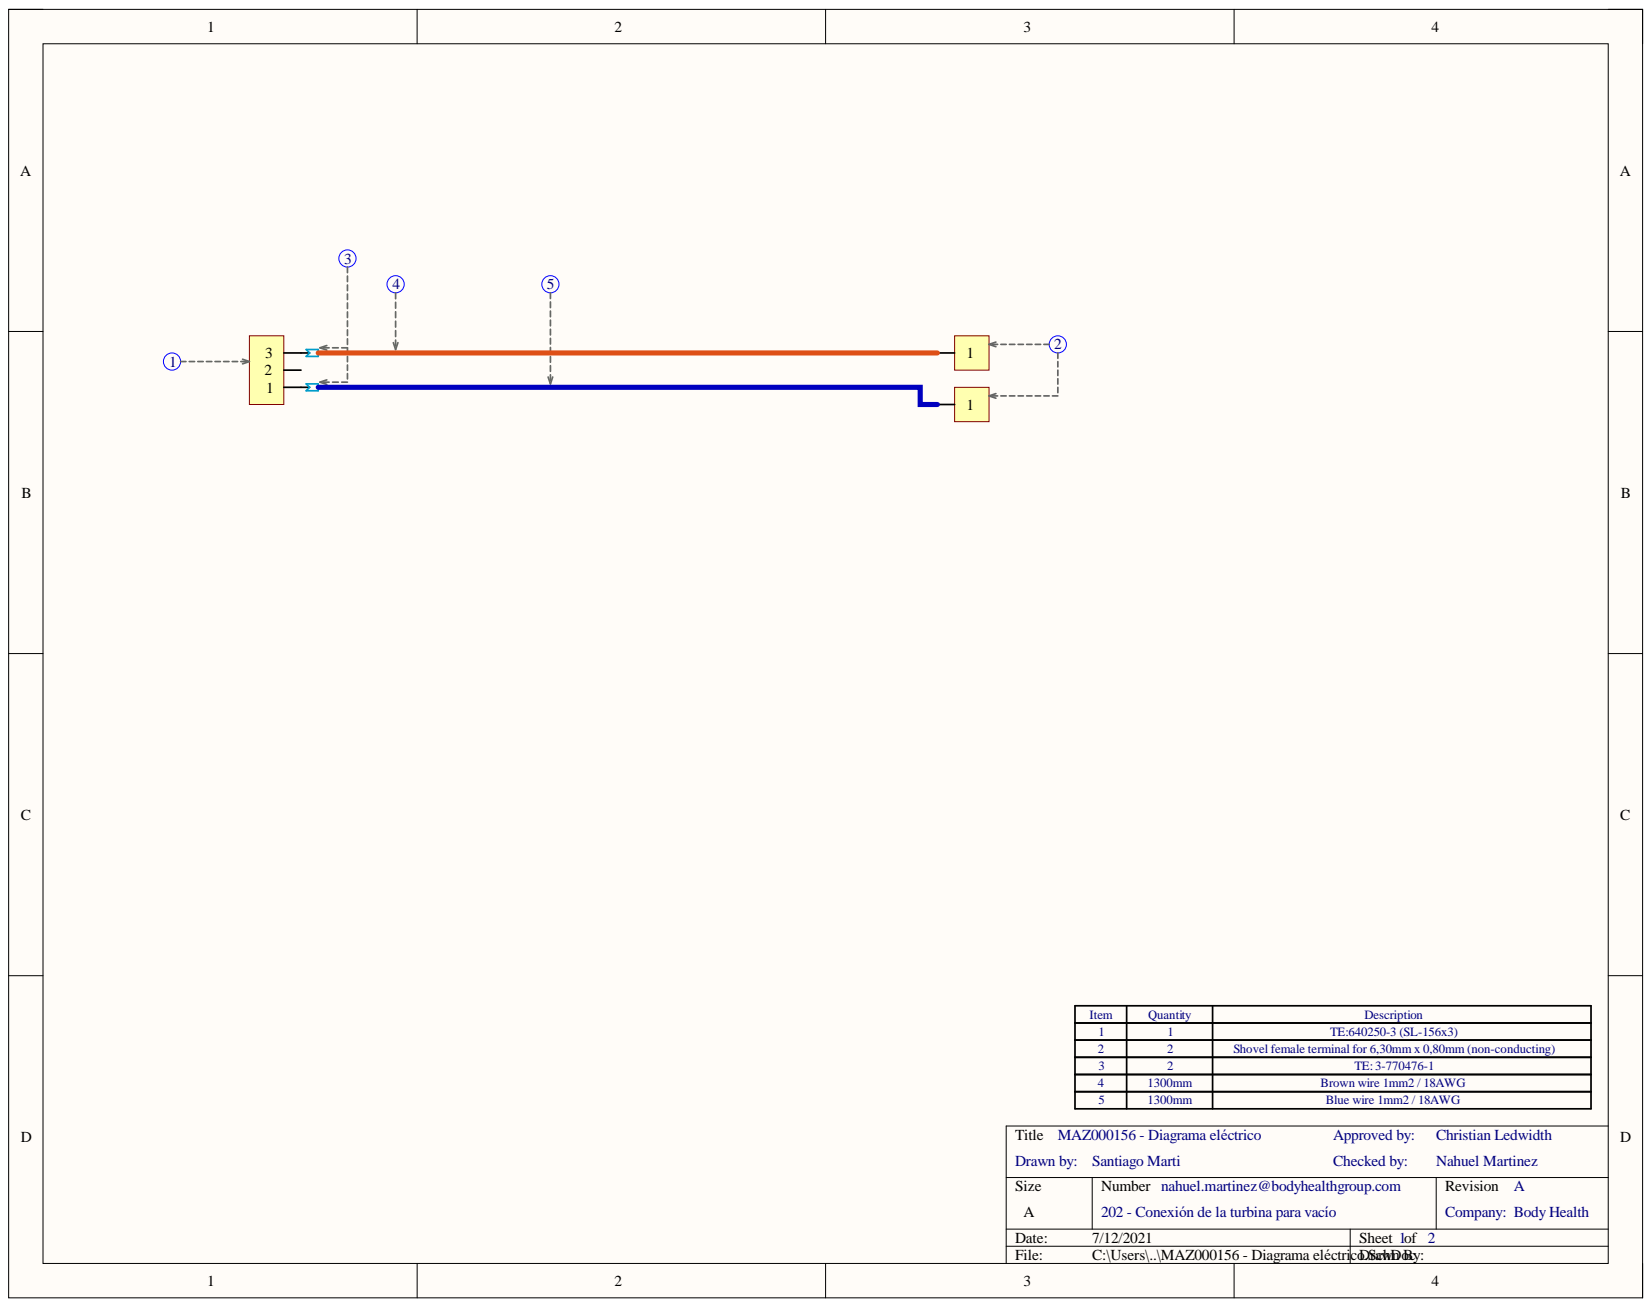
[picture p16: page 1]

Item | Quantity | Description
1 | 1 | TE:640250-3 (SL-156x3)
2 | 2 | Shovel female terminal for 6,30mm x 0,80mm (non-conducting)
3 | 2 | TE: 3-770476-1
4 | 1300mm | Brown wire 1mm2 / 18AWG
5 | 1300mm | Blue wire 1mm2 / 18AWG

Size A | Number nahuel.martinez@bodyhealthgroup.com 202 - Conexión de la turbina para vacío | Revision A Company: Body Health

Date: 7/12/2021 | Sheet of 1 2
File: C:\Users\..\MAZ000156 - Diagrama eléctricoDr.ScawhDon Bcy:

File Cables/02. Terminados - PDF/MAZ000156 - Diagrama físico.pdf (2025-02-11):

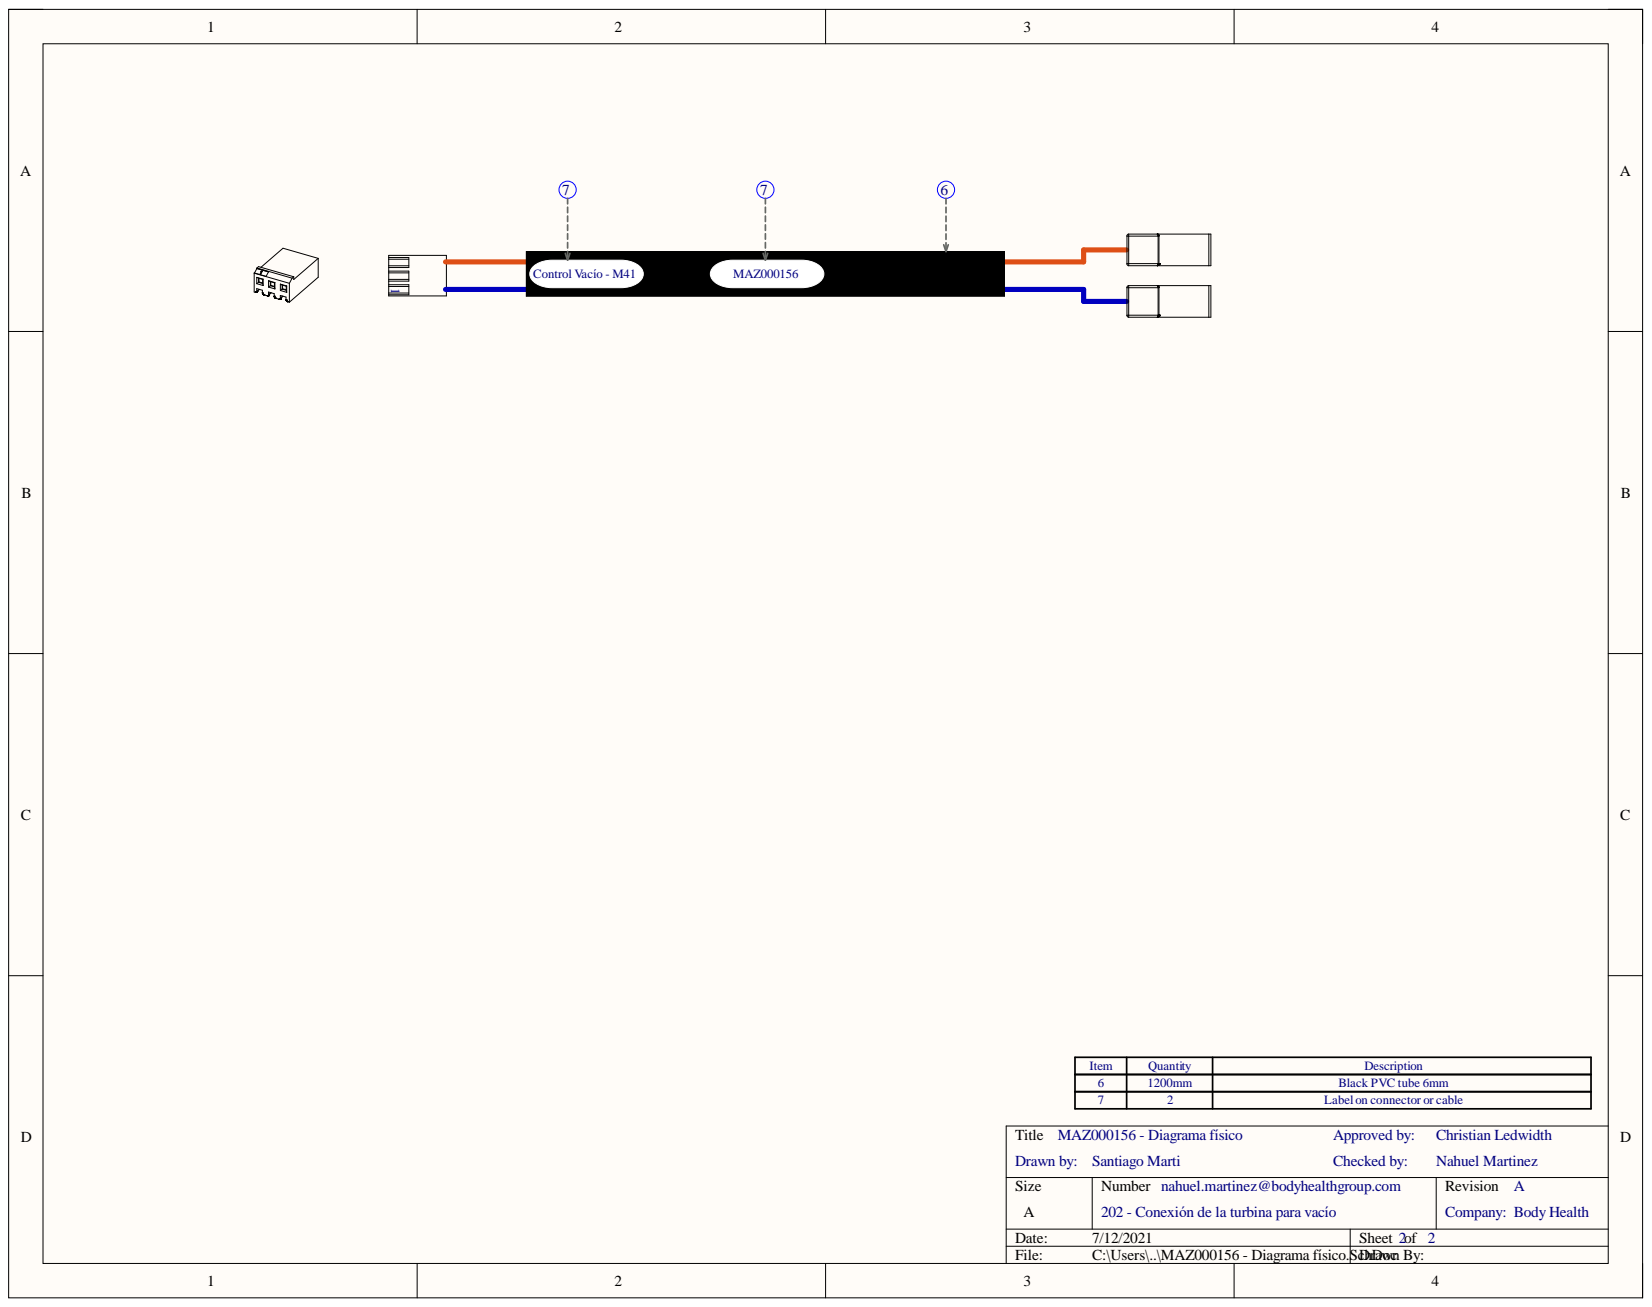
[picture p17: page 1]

Item | Quantity | Description
6 | 1200mm | Black PVC tube 6mm
7 | 2 | Label on connector or cable

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

Date: 7/12/2021 | Sheet of 2 2
File: C:\Users\..\MAZ000156 - Diagrama físico.ScDrhDoawcn By:

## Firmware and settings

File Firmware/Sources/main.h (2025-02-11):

/* Including needed modules to compile this module/procedure */
#include "Cpu.h"
#include "Events.h"
#include "Vtpm1ovf.h"
/* Include shared modules, which are used for whole project */
#include "PE_Types.h"
#include "PE_Error.h"
#include "PE_Const.h"
#include "IO_Map.h"

/* User includes (#include below this line is not maintained by Processor Expert) */
#include "Display.h"
#include "DS18S20.h"
#include "Timer.h"







		/****************************************************************************************************************/
		/*			  						DEFINICIONES DE NUEVOS OBJETOS Y DATOS										*/
		/****************************************************************************************************************/

// Definicion de los estados para elegir o probar el cable
typedef enum saraza {
	DEFINIENDO_1_CIFRA = 0,
	DEFINIENDO_2_CIFRA,
	DEFINIENDO_3_CIFRA,
	PROBANDO_CABLE
} estadosPrograma;

// Definicion de los targets para las direcciones de los multiplexores
typedef enum targetMult {
	
	// Lugar 1
	CABLE_MAZO_001 = 0,
	CABLE_MAZO_041,
	CABLE_MAZO_105,
	
	// Lugar 2
	CABLE_MAZO_002,
	CABLE_MAZO_042,
	CABLE_MAZO_072,
	CABLE_MAZO_106,
	
	// Lugar 3
	CABLE_MAZO_003,
	CABLE_MAZO_004,
	CABLE_MAZO_005,
	CABLE_MAZO_026,
	CABLE_MAZO_043,
	CABLE_MAZO_044,
	CABLE_MAZO_060,
	CABLE_MAZO_073,
	CABLE_MAZO_074,
	CABLE_MAZO_110,
	
	// Lugar 4
	CABLE_MAZO_006,
	CABLE_MAZO_007,
	CABLE_MAZO_045,
	CABLE_MAZO_046,
	CABLE_MAZO_075,
	CABLE_MAZO_107,
	
	// Lugar 5
	CABLE_MAZO_012,
	CABLE_MAZO_051,
	
	// Lugar 6
	CABLE_MAZO_025,
	CABLE_MAZO_071,
	CABLE_MAZO_083,
	
	// Lugar 7
	CABLE_MAZO_047,
	CABLE_MAZO_076,
	
	// Lugar 8
	CABLE_MAZO_011,
	CABLE_MAZO_050,
	CABLE_MAZO_108,
	
	// Lugar 9
	CABLE_MAZO_023,
	CABLE_MAZO_081,
	
	// Lugar 10
	CABLE_MAZO_021,
	CABLE_MAZO_079,
	
	// Lugar 11
	CABLE_MAZO_031,

	// Lugar 12
	CABLE_MAZO_038,
	
	// Lugar 13
	CABLE_MAZO_078,
	
	// Lugar 14
	CABLE_MAZO_030,
	CABLE_MAZO_064,

	// Lugar 15
	CABLE_MAZO_090,

	// Lugar 16
	CABLE_MAZO_009,
	CABLE_MAZO_048,
	CABLE_MAZO_077,
	
	// Lugar 17
	CABLE_MAZO_022,
	
	// Lugar 18
	CABLE_MAZO_024,
	CABLE_MAZO_109,
	
	// Lugar 19
	CABLE_MAZO_082,
	
	// Lugar 20
	CABLE_MAZO_096,
	
	// Lugar 21
	CABLE_MAZO_097_A,
	CABLE_MAZO_097_B,
	
	// Lugar 23
	CABLE_MAZO_032,
	CABLE_MAZO_066,
	
	// Lugar 24
	CABLE_MAZO_111,
	
	// Lugar 25
	CABLE_MAZO_035,
	
	// Lugar 26
	CABLE_MAZO_034,
	
	// Lugar para el cable de telefono
	CABLE_MAZO_000
	
} targetMultiplexores;


// Definicion para interpretar mas facilmente los errores de los pernos
typedef enum erroresPernos {
	PERNO_SIN_ERRORES = 0,
	PERNO_ABIERTO,
	PERNO_CORTO_CIRCUITO,
	PERNO_CORTO_CIRCUITO_CARCAZA,
	PERNO_SIN_ALTERNANCIA,
	PERNO_CORTOCIRCUITO_CON_5V
} resultadoPernos;

// Definicion para interpretar mas facilmente los estados de los pulsadores
typedef enum teclaPresionada {
	TECLA_DERECHA_O_ABAJO = 0,
	TECLA_IZQUIERDA_O_ARRIBA,
	TECLA_ACEPTAR,
	TECLA_CANCELAR,
	TECLA_SELECCIONAR_MENU
} estadosTeclas;


// Definicion de la estructura para manejar los pernos como una matriz mas facil de interpretar
typedef struct	{
	bool	contactos[ 16 + 1 ];
	char	totalDeContactos;
} pernosObj;



		/****************************************************************************************************************/
		/*				  						DEFINICIONES DE LAS CONEXIONES											*/
		/****************************************************************************************************************/

// Defines para los LEDs
#define  	LED_ROJO_DIRECCION						PTCDD_PTCDD3
#define  	LED_ROJO_PIN							PTCD_PTCD3
#define  	LED_VERDE_DIRECCION						PTCDD_PTCDD5
#define  	LED_VERDE_PIN							PTCD_PTCD5

// Defines para los pulsadores
#define  	PULSADOR_S1_DIRECCION					PTEDD_PTEDD6
#define  	PULSADOR_S1_PIN							PTED_PTED6
#define  	PULSADOR_S1_PUERTO						PTED
#define		PULSADOR_S1_MASCARA						PTED_PTED6_MASK		// Es para leer solo el pin del pulsador

#define  	PULSADOR_S2_DIRECCION					PTEDD_PTEDD4
#define  	PULSADOR_S2_PIN							PTED_PTED4
#define  	PULSADOR_S2_PUERTO						PTED
#define		PULSADOR_S2_MASCARA						PTED_PTED4_MASK		// Es para leer solo el pin del pulsador

#define  	PULSADOR_S3_DIRECCION					PTEDD_PTEDD7
#define  	PULSADOR_S3_PIN							PTED_PTED7
#define  	PULSADOR_S3_PUERTO						PTED
#define		PULSADOR_S3_MASCARA						PTED_PTED7_MASK		// Es para leer solo el pin del pulsador

#define  	PULSADOR_S4_DIRECCION					PTEDD_PTEDD5
#define  	PULSADOR_S4_PIN							PTED_PTED05
#define  	PULSADOR_S4_PUERTO						PTED
#define		PULSADOR_S4_MASCARA						PTED_PTED5_MASK		// Es para leer solo el pin del pulsador
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

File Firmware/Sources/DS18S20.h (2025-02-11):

/****************************************************************************************************/
/****************************************************************************************************/
/* 						DEFINICIONES PARA MANEJAR LOS SENSORES DE TEMPERATURA 						*/
/****************************************************************************************************/
/****************************************************************************************************/

// Includes
#include "IO_Map.h"
#include "PE_Types.h"



// Defines para los sensores que van a ser practicamente fijos en la placa:

	/*********************************************************************/
	/* *** Sensores para la placa de pruebas completas de manillares *** */
	/*********************************************************************/
/*
	// Sensor soldado directamente
	#define	DS18S20_SOLDADO_BYTE_0		0x10
	#define	DS18S20_SOLDADO_BYTE_1		0x0B
	#define	DS18S20_SOLDADO_BYTE_2		0x38
	#define	DS18S20_SOLDADO_BYTE_3		0x5F
	#define	DS18S20_SOLDADO_BYTE_4		0x03
	#define	DS18S20_SOLDADO_BYTE_5		0x08
	#define	DS18S20_SOLDADO_BYTE_6		0x00
	#define	DS18S20_SOLDADO_BYTE_7		0x69

	// Sensor para la manguera
	#define	DS18S20_MANGUERA_BYTE_0		0x10
	#define	DS18S20_MANGUERA_BYTE_1		0x59
	#define	DS18S20_MANGUERA_BYTE_2		0x2D
	#define	DS18S20_MANGUERA_BYTE_3		0x5F
	#define	DS18S20_MANGUERA_BYTE_4		0x03
	#define	DS18S20_MANGUERA_BYTE_5		0x08
	#define	DS18S20_MANGUERA_BYTE_6		0x00
	#define	DS18S20_MANGUERA_BYTE_7		0x87

	// Sensor para el lado caliente del manillar
	#define	DS18S20_LADO_CALIENTE_BYTE_0		0x10
	#define	DS18S20_LADO_CALIENTE_BYTE_1		0x85
	#define	DS18S20_LADO_CALIENTE_BYTE_2		0x4D
	#define	DS18S20_LADO_CALIENTE_BYTE_3		0x5F
	#define	DS18S20_LADO_CALIENTE_BYTE_4		0x03
	#define	DS18S20_LADO_CALIENTE_BYTE_5		0x08
	#define	DS18S20_LADO_CALIENTE_BYTE_6		0x00
	#define	DS18S20_LADO_CALIENTE_BYTE_7		0x2F
*/

	/******************************************************************************************/
	/* *** Sensores para la placa de pruebas reducidas con el display con todos los pines *** */
	/******************************************************************************************/

	// Sensor soldado directamente
	#define	DS18S20_SOLDADO_BYTE_0		0x10
	#define	DS18S20_SOLDADO_BYTE_1		0xBE
	#define	DS18S20_SOLDADO_BYTE_2		0xA2
	#define	DS18S20_SOLDADO_BYTE_3		0x79
	#define	DS18S20_SOLDADO_BYTE_4		0x03
	#define	DS18S20_SOLDADO_BYTE_5		0x08
	#define	DS18S20_SOLDADO_BYTE_6		0x00
	#define	DS18S20_SOLDADO_BYTE_7		0xF6

	// Sensor para la manguera
	#define	DS18S20_MANGUERA_BYTE_0		0x10
	#define	DS18S20_MANGUERA_BYTE_1		0x59
	#define	DS18S20_MANGUERA_BYTE_2		0x2D
	#define	DS18S20_MANGUERA_BYTE_3		0x5F
	#define	DS18S20_MANGUERA_BYTE_4		0x03
	#define	DS18S20_MANGUERA_BYTE_5		0x08
	#define	DS18S20_MANGUERA_BYTE_6		0x00
	#define	DS18S20_MANGUERA_BYTE_7		0x87

	// Sensor para el lado caliente del manillar
	#define	DS18S20_LADO_CALIENTE_BYTE_0		0x10
	#define	DS18S20_LADO_CALIENTE_BYTE_1		0x79
	#define	DS18S20_LADO_CALIENTE_BYTE_2		0x80
	#define	DS18S20_LADO_CALIENTE_BYTE_3		0x5F
	#define	DS18S20_LADO_CALIENTE_BYTE_4		0x03
	#define	DS18S20_LADO_CALIENTE_BYTE_5		0x08
	#define	DS18S20_LADO_CALIENTE_BYTE_6		0x00
	#define	DS18S20_LADO_CALIENTE_BYTE_7		0xEE


	/**************************************************************************************/
	/* *** Sensores para la placa de pruebas reducidas con el display con menos pines *** */
	/**************************************************************************************/
/*
	// Sensor soldado directamente
	#define	DS18S20_SOLDADO_BYTE_0		0x10
	#define	DS18S20_SOLDADO_BYTE_1		0x0E
	#define	DS18S20_SOLDADO_BYTE_2		0xD4
	#define	DS18S20_SOLDADO_BYTE_3		0x7A
	#define	DS18S20_SOLDADO_BYTE_4		0x03
	#define	DS18S20_SOLDADO_BYTE_5		0x08
	#define	DS18S20_SOLDADO_BYTE_6		0x00
	#define	DS18S20_SOLDADO_BYTE_7		0x88

	// Sensor para la manguera
	#define	DS18S20_MANGUERA_BYTE_0		0x10
	#define	DS18S20_MANGUERA_BYTE_1		0x59
	#define	DS18S20_MANGUERA_BYTE_2		0x2D
	#define	DS18S20_MANGUERA_BYTE_3		0x5F
	#define	DS18S20_MANGUERA_BYTE_4		0x03
	#define	DS18S20_MANGUERA_BYTE_5		0x08
	#define	DS18S20_MANGUERA_BYTE_6		0x00
	#define	DS18S20_MANGUERA_BYTE_7		0x87

	// Sensor para el lado caliente del manillar
	#define	DS18S20_LADO_CALIENTE_BYTE_0		0x10
	#define	DS18S20_LADO_CALIENTE_BYTE_1		0xDD
	#define	DS18S20_LADO_CALIENTE_BYTE_2		0x83
	#define	DS18S20_LADO_CALIENTE_BYTE_3		0x5F
	#define	DS18S20_LADO_CALIENTE_BYTE_4		0x03
	#define	DS18S20_LADO_CALIENTE_BYTE_5		0x08
	#define	DS18S20_LADO_CALIENTE_BYTE_6		0x00
	#define	DS18S20_LADO_CALIENTE_BYTE_7		0x20
*/




/* Macros para las demoras */
#define 	DEMORA_1US				asm( nop ); asm( nop ); asm( nop ); asm( nop );
#define 	DEMORA_480US			TPM1CNT = 0;	while( TPM1CNT < 0x01D8 )	{};		// Para el reset
#define 	DEMORA_410US			TPM1CNT = 0;	while( TPM1CNT < 0x0195 )	{};		// Para el reset
#define 	DEMORA_70US				TPM1CNT = 0;	while( TPM1CNT < 0x0041 )	{};		// Para el reset
#define 	DEMORA_10US				TPM1CNT = 0;	while( TPM1CNT < 0x0005 )	{};		// Para escribir un 1
#define 	DEMORA_55US				TPM1CNT = 0;	while( TPM1CNT < 0x0032 )	{};		// Para escribir un 1
#define 	DEMORA_65US				TPM1CNT = 0;	while( TPM1CNT < 0x003C )	{};		// Para escribir un 0
#define 	DEMORA_5US				TPM1CNT = 0;	while( TPM1CNT < 0x0003 )	{};		// Para escribir un 0
#define 	DEMORA_50mS				TPM1CNT = 0;	while( TPM1CNT < 0xC350 )	{};		// Para darle tiempo al sensor a que convierta la temperatura


/* Defines para el sensor */

#define  	DS18S20_DIRECCION		PTEDD_PTEDD1
#define  	DS18S20_PIN				PTED_PTED1
#define  	DS18S20_PUERTO			PTED
#define		DS18S20_MASCARA			PTED_PTED1_MASK		// Es para leer solo el pin del sensor
#define		LONGITUD_ROM_BYTES		8
#define		LONGITUD_ROM_BITS		64
#define		LONGITUD_RESPUESTA		9
#define		TEMPERATURA_BYTE_BAJO	0
#define		TEMPERATURA_BYTE_ALTO	1
#define		TOTAL_DE_SENSORES		5
#define		BYTES_TIPO_DE_SENSOR	0

#define		NO_MAS_COLISIONES		0xFF


typedef enum errores {
	SIN_ERROR = 0,
	PULSO_RESET,
	BUS_SIN_SENSORES,
	ORDEN_INCORRECTA,
	SENSOR_INCORRECTO,
	NO_MAS_SENSORES,
	TEMPERATURA_PROHIBIDA,
	NO_ENCONTRADO_SENSOR_SOLDADO,
	NO_ENCONTRADO_SENSOR_LADO_CALIENTE,
	NO_ENCONTRADO_SENSOR_MANGUERA,
	NO_ENCONTRADO_SENSOR_EXTERNO
} erroresDS18S20; 

typedef enum ubicacionSensores {
	SENSOR_SOLDADO_EN_PLACA = 0,
	SENSOR_PARA_LADO_CALIENTE,
	SENSOR_PARA_LA_MANGUERA,
	SENSOR_MANILLAR,
	SENSOR_EXTERNO
} posicionSensores;

// Definicion de una estructura para manejar mas facilmente a los sensores, como si fuesen un objeto
typedef struct
{
	unsigned char 	ROM[8];
	int16_t			temperatura;	// Se almacena el valor multiplicado por 10, para evitar usar decimales
	bool			presente;
}sensorDS18S20;



/* **** Defines para las instrucciones de comando de los sensores **** */

// Instruccion para iniciar la conversion de temperatura
#define		INSTRUCCION_DS18S20_INICAR_CONVERSION_T			0
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

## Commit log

2025-02-11 Se agregan los planos de los cables realizados en Altium
    [MAZ000153 - Diagrama eléctrico.SchDoc, MAZ000153 - Diagrama físico.SchDoc, MAZ000154 - Diagrama eléctrico.SchDoc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]
2025-02-11 Se agrega el código fuente del firmware para el microncontrolador
2025-02-11 Se agregan los archivos de Altium para la creación de los PCBs
    [ProbadorDeCables.PrjPcb, ProbadorDeCables.xlsx, ProbadorDeCables_Accesorios_A.SchDoc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]
2025-02-11 Se agregan imágenes de muestra de los planos
2025-02-11 Se actualiza la descripción del proyecto
2025-02-11 Cambios menores en la visualización
